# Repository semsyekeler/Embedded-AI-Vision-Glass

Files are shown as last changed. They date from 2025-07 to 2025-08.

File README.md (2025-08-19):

<!-- Bu bir test ve örnek README dosyasıdır. -->

<div align="center">
  <h1 align="center">Gömülü Yapay Zeka Görü Gözlüğü (EGG)</h1>
</div>

---

### 📜 İçindekiler

1.  [**Proje Hakkında**](#-proje-hakkında)
    -   *Projenin çıkış noktası ve misyonu.*
2.  [**Teknik Mimari**](#️-teknik-mimari)
    -   *Sistemin genel yapısı ve kullanılan teknolojiler.*
3.  [**Donanım Detayları ve Montaj**](#-donanım-detayları-ve-montaj)
    -   *Kullanılan bileşenler ve montaj süreci.*
4.  [**Canlı Demolar**](#-canlı-demolar-ve-vitrin)
    -   *Projenin çalıştığını gösteren videolar.*

---
<br>

## 🏆 Proje Hakkında

Bu proje, görme engelli bireylerin dünyayı algılama şeklini kökten değiştirmek amacıyla, tamamen kişisel imkanlarla sıfırdan hayata geçirilmiş bir teknoloji manifestosudur. Misyonumuz, sadece "engel var" diyen bir cihaz değil, kullanıcıya **"önündeki tabelada 'acil çıkış' yazıyor"** diyebilen, çevresini **anlamlandıran ve betimleyen** bir yardımcı yaratmaktır. Bu vizyon, uluslararası bir yarışmada alınan derece ile tescillenmiştir.

Projenin temel amacı, teknolojiyi kullanarak görsel dünyayı sesli bilgiye dönüştürmek ve bu sayede kullanıcı için daha erişilebilir bir çevre yaratmaktır.

<br>
<br>
<br>
<br>
<br>

## 🛠️ Teknik Mimari

EGG projesi, donanım, gömülü yazılım, bulut ve mobil katmanları bir araya getiren tam kapsamlı bir IoT çözümüdür. Projenin teknik kararlarını ve yapısını aşağıdaki notlu şema özetlemektedir.

<p align="center">
  Açıklamalı Devre Şeması
</p>

Sistemin kalbinde, görevleri verimli bir şekilde dağıtan **Çift Mikrodenetleyici Mimarisi** (ESP32 + ESP32-CAM) yer alır. Tüm ağır yapay zeka işlemleri, maliyeti ve cihaz yükünü en aza indirmek için **AWS (Amazon Web Services)** üzerinde "sunucusuz" bir mimaride çalışır.

<br>
<br>
<br>
<br>
<br>

### 🔩 Donanım Detayları ve Montaj

Bu bölümde, projenin fiziksel olarak nasıl hayata geçtiğini görebilirsiniz. Tüm bileşenler, bütçe dostu ve erişilebilir olmaları göz önünde bulundurularak seçilmiştir.

*   **Ana Kontrolcü:** ESP-WROOM-32
*   **Kamera İşlemcisi:** ESP32-CAM
*   **Güç Yönetimi:** TP4056 Şarj Modülü + 18650 Lityum Pil + 5V Step-Up Konvertör
*   **Ses Sistemi:** Modifiye edilmiş (hacklenmiş) bir Bluetooth kulaklık PCB'si

<p align="center">
  Montaj Aşaması
  <br>
  <em>Tüm bileşenlerin elle birleştirildiği "çıplak" prototipin ilk halleri.</em>
</p>

<br>
<br>
<br>
<br>
<br>

## 🖼️ Canlı Demolar ve Vitrin

Projenin işlevselliğini ve son halini gösteren YouTube videoları:

| Final Prototip Turu | Canlı Asistan Testi |
| :---: | :---: |
| _Gözlüğün son halinin her açıdan incelendiği ürün turu videosu._ | _Sesle etkinleştirilen fener özelliğinin canlı testini içeren demo videosu._ |
| <a href="https://www.youtube.com/watch?v=MX3VzD0-spU" target="_blank">Final Prototip Turu Videosu</a> | <a href="https://www.youtube.com/watch?v=o3IA8lo6HuY" target="_blank">Canlı Asistan Testi Videosu</a> |

<br>
<br>
<br>
<br>
<br>

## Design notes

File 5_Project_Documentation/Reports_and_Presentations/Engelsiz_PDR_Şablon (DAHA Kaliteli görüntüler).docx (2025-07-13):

# TEKNOFEST

# HAVACILIK, UZAY VE TEKNOLOJİ FESTİVALİ

ENGELSİZ YAŞAM TEKNOLOJİLERİ YARIŞMASI

PROJE DETAY RAPORU

## PROJE ADI: ENGELSİZ GÖRÜ GÖZLÜĞÜ (EGG)

TAKIM ADI: ŞAH

Başvuru ID: 446246

TAKIM SEVİYESİ: Lise

İçindekiler

1. Proje Özeti (Proje Tanımı)

EGG görme eyleminde sorun yaşayan bireylerin akıllı gözlük teknolojileriyle hayatlarını kolaylaştırmayı çalışıyor, görme eyleminde sorun yaşayan bireylerin hayatlarında yapay zeka destekli bir yardımcı oluyor.

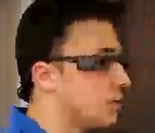
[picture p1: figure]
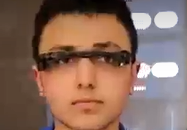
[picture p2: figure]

  1.1. Belge İçeriği

BUbelge şuanları içeriyor

  1.2. Tasarım

EGG’nin toplam ağırlığı 93g olmak üzere dış tasarımsal açıdan çok ilkel, gelişimini tamamlamamış halde EGG şuanda bir 3d sinema gözlüğünün çerçevesinin alt kısımlarının kesilmesiyle oluşturulmuş kasayı kullanıyor. Üzerinde sağ ve sol olmak üzere iki mantar LED bulunmakta üzerinde laptop batarya kutusundan çıkmış, ömrü azalmış, üzerinde 2Ah yazan bir adet 18650 batarya bulunmakta ve değiştirilebillir olması için 18650 batarya yatağı bulunmakta ve bataryanın şarj edilebilir olması için ve herhangi bir kısa devre vb. durumda korumuya da alması için bms devreli olan şarj devresi TP4056 bulunmakta ama micro usb soketi pil yatağının soluna konumladırılmış vaziyette -daha kolay şarj edilebilir olması açısından- . Üzerinde bir adet ESP32-WROOM bulunmakta ve bir adetESP32-CAM olarak adlandırılan geliştirme kartı bulunuyor ESP32’yi tercih etme sebeplerim uygun fiyatlı ve kablosuz iletişim kurma olanaklarını bünyesinde hazır olarak bulundurması (WiFi, Bluetooth 4.2, BLE), daha hızlı olması ve kapasitif ölçüm yapabilmesi. Normalde sadece ESP32-CAM yetecekken bir adet daha ESP32 kullanmamım sebebi ESP32-CAM üzerinde bulununan hafıza kartı soketini kullanınca I/O olarak kullanabileceğim pinin kalmaması ve ESP32-CAM ile WiFi üzerinden yayın yaparken Blutooth’u kullanmak istersem hata vermesiydi bunun üzerine iki adet ESP32 kullanarak birbirlerini de UART üzerinden haberleştirerek bu sorunu çözdüm. Üzerinde iki adet dokunmatik yüzey bulunuyor bu yüzeyleri ESP32’nin kapasitif ölçüm yapabilen pinleri ile kontrol ediyorum ve hem elimizle daha kolay erişebilinmesi hem de daha stabil çalışması adına yüzeyleri nikel şeritten parça keserek oluşturdum. Ses işlevleri içinse mikrofon kalitesi çok iyi olan, sesi çok iyi veren ve alan ve bu özelliklerine rağmen telefoncularda en ucuz alabileceğiniz seviyede olan bluetooth kulaklığı keşfettim ve kullandım hazır kullanmamın bana katkısı şu oldu hali hazırda ses kalitesi iyi olduğundan sesi yazıya çevirme işlemlerinde daha iyi tanımlama sağladı ama video çekimi yapacağım zaman mikrofon bluetooth kulaklıkta olduğundan ses alamayı eş zamanlı yapamadım. EGG özünde bir akıllı gözlük olduğundan akıllı gözlük gibi de kullanılabiliyor. Dokunmatik yüzey ilk başta bir adet vardı sadece akıllı gözlük işlevlerini yapıyordu yapay zeka fonksiyonlarını uygulama üzerinden buton ile ya da sesli asistan ile veriyorduk ama bu hem süreyi uzatıyordu hem de yolda giderken sesli bir şekilde söylenmesi iyi karşınmayacağından ikinci yüzeyi ekledim ve test ettim Arduino Uno’yu programlayıcı olarak kullanarak ESP32’ye test programını atıp yüzeyi test ettim.

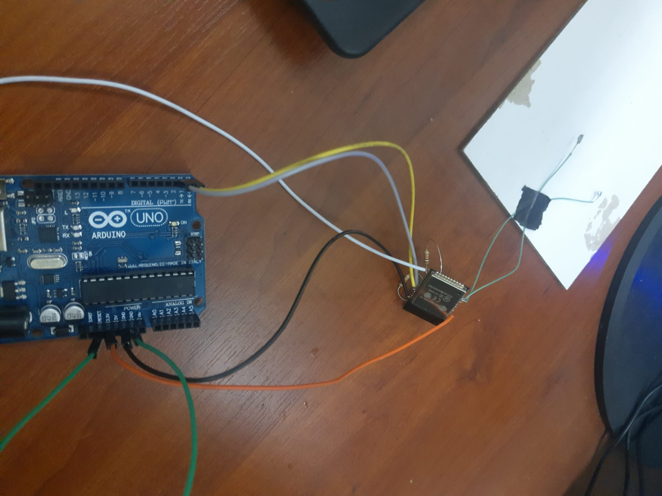
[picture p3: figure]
Yüzeyler

Sarı işaretli yerde olan şey ESP32, siyah işaretli olan yerse dokunmatik yüzeylerimiz.

Yüzeyler şöyle çalışıyordu her birinin 4 işlevi vardı tek dokunma, çift dokunma, üç dokunma ve basılı tutma ama gelin görünki tek yüzeyde çalışan bu mantık diğer yüzeyle olunca çalışmadı aslında sebebi interrupt kullanmamamdı kullanmayı denedim ama kapasitif ölçümde çalıştıramadım bu beni daha iyi bir sisteme itti buradaki sistem sabitti benimde aklıma değişebilir bir sistem geldi yine iki yüzey olacaktı ilk yüzey 4 işlevli olan sistemi kullanacaktı ama kullanırken çağıracağı fonksiyonlar index diye bir değişkene bağlı olacaktı bu sayede indexin değişimiyle dinamik fonksiyonları elde edecektim ikinci yüzey ise indexi arttıracaktı ve basılı tuttuğunda sıfırlayacaktı bunu bu şekilde yaparak dinamik fonksiyonları çalışır bir sisteme döktüm.

Dokunmatik yüzey ve işlevleri index değimine göre tablodaki gibidir

| İndex = 0 | İndex = 1 | İndex =2 | İndex =3
1. Dokunuş | Sesli Asistan | Sesli Asistan | Sesli Asistan | Sesli Asistan
2. Dokunnuş | Fotoğraf Çek | Ses başlat/durdur çağrıyı kabul et | Ortam Analizi | Para Tespiti
3. Dokunuş | Yayina Geç | Çağrıyı reddet | Metin Analizi | Yüz Tanıma
Basılı tutma | LED aç/kapa | Kulaklığı aç/kapa | Metin Çevirisi | Şu anda nerdeyim

Sesli asistan fonksiyonu Bluetooth ile bağladığımız telefona veri göndererek kodladığım sesli asistanı çağırır.

Fotoğraf Çek fonksiyonu sisteme fotoğrafı çekip ESP32-CAM'e taktığımız sd karta fotoğrafı kaydeder ve ismini çekildiği tarih ve saati olarak yazar.

LED aç/kapa fonksiyonu üzerinde bulunan mantar ledlerin durumu her neyse zıttına çevirir.

Ses başlat/durdur fonksiyonu çağrıyı kabul et fonksiyonu kulaklıklardan bildiğimiz play/pause işlevini görür.

Çağrıyı reddet fonksiyonu daha uzun süre kulaklığa tetik vererek çağrıyı reddeder.

Kulaklığı aç/kapa 3 saniye boy kulaklığa tetik vererek kulaklığı açar veya kapatır.

Ortam analizi fonksiyonu telefonun hotspotunu açar, fotoğraf çeker, sunucuya atar ve sunucuda işlenir sonra tespit edilen nesneleri sayılarıyla birlikte döndürür android uygulamaysa döndürülen bilgiyi alır ve okutur.

Metin analizi fonksiyonu telefonun hotspotunu açar, fotoğraf çeker, sunucuya atar ve sunucuda işlenir sonra tespit edilen metinleri okutur.

Metin çevirisi fonksiyonu aynı metin analizi ile aynı sistemi kullanır ama sesli okutmadan önce Google çeviriye metini yollar ve türkçeye çevirip okutur.

Para tespiti fonksiyonu telefonun hotspotunu açar, fotoğraf çeker, sunucuya atar ve sunucuda banknotu tespit eder ve sonucu telefona okutur örneğin; “200 türk lirası” şeklinde okutur.

Yüz tanıma fonksiyonu telefonun hotspotunu açar, fotoğraf çeker, sunucuya atar ve sunucuda yüz tespit edilir, yüz eğer evvelden tanıtılmışsa o kişi nasıl kaydedilmişse onun ismini okutur, eğer kaydedilmemişse o kişinin ismini söyleyip kayıt edebiliriz.

Komutları mobil uygulama ile de verebiliriz

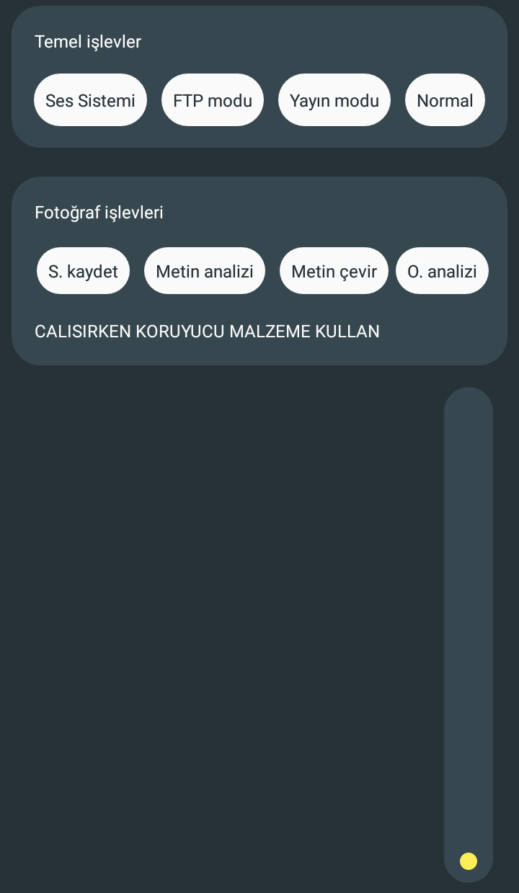
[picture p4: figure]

S. kaydet butonu fotoğrafı çeker ve linkini verir ve size fotoğrafı gösterir.

FTP modu butonu telefonun hotspotunu açar, ve gözlüğü ona bağlatır sonra sd kart dizinine erişmemizi sağlar.

Komutları sesli komut ile de verebiliriz ama hem gecikme hem de yanlış anlamalar sebebiyle yavaş ve yavan kalıyor.

Yazılım

Yazılım, tasarımdaki kısımları işletiyor işletme sistemin yukarıdan anlayabileceğiniz gibi yazılım kısmı temel olarak üç kısımdan oluşuyor; gözlükteki yazılım, mobil uygulamadaki ve sunucudaki yazılım.

Gözlüğün Yazılımı

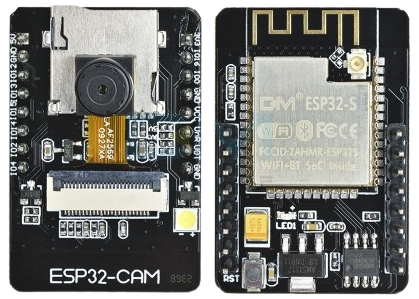
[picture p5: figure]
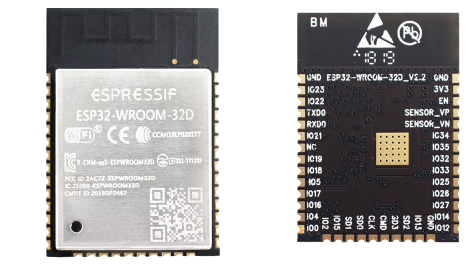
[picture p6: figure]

Gözlüğün yazılımı bu iki kartın içerisinde bulunuyor. Bu yazılımları mantıken ikiye ayırabiliriz; ilki kamera, WiFi ve SD kartı ile işlevleri kontrol eden kart yani ESP32-CAM diğeriyse ESP32-WROOM bu kart bileşenleri, Bluetooth’tan gelen verileri, Dokunmatik yüzeyleri ve ESP32-CAM'i kontrol eden kart. ESP32WROOM’a gelen veri eğer ESP32-CAM ile alakalı ise UART üzerinden iletir ve eğer oradan veri gelirse o veriyi alır telefona iletilecek ise iletir eğer kendisi kullanacaksa kullanır.

ESP32-WROOM' dan temel kodlar (Kodları okuyabilmek için büyütebilirsiniz)

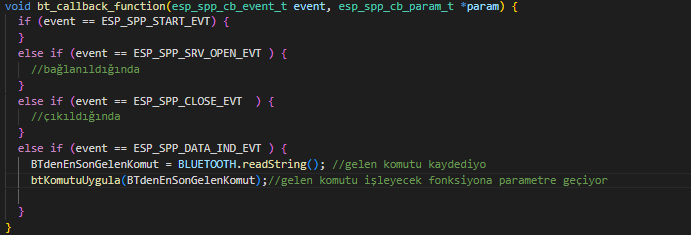
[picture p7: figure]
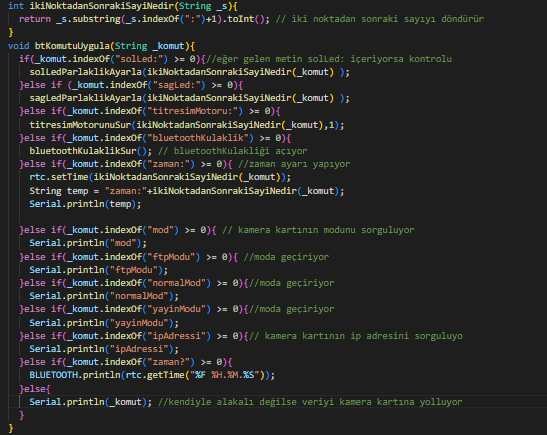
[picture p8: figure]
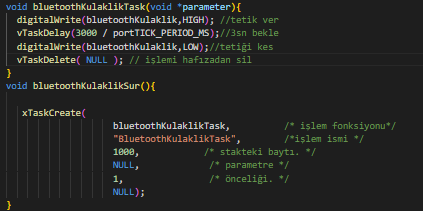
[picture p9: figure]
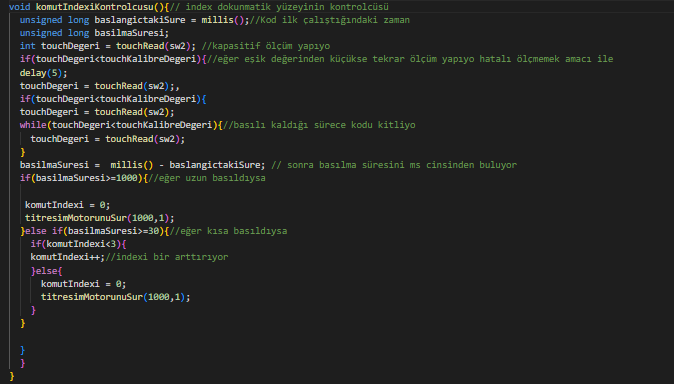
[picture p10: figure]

ESP32-CAM’den bazı temel kodlar

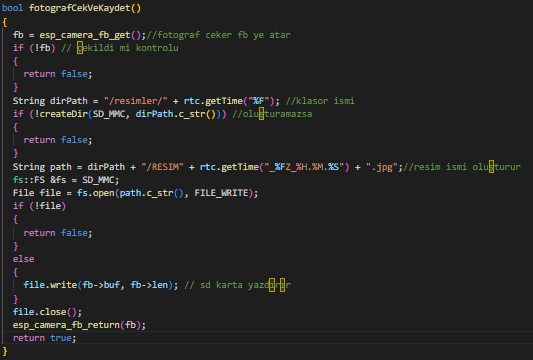
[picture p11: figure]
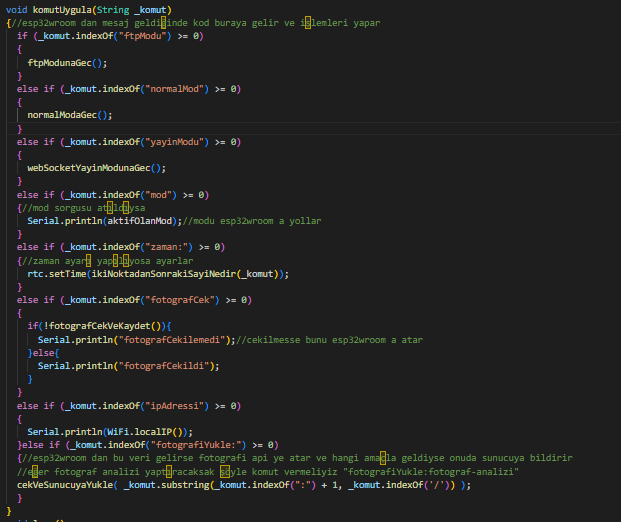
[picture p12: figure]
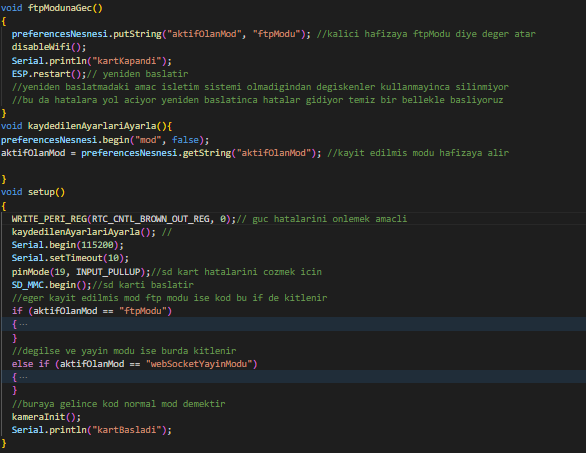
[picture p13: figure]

Mobil uygulama kodları

Mobil uygulama kodları temel olarak gözlükten gelen verileri alır işleve çevirir ya da emir verir ve sunucudan gelecek olan yanıtı bekler işlevler yaptırır

Arayüz kontrollerinin gozluge aktardığımız kodlar

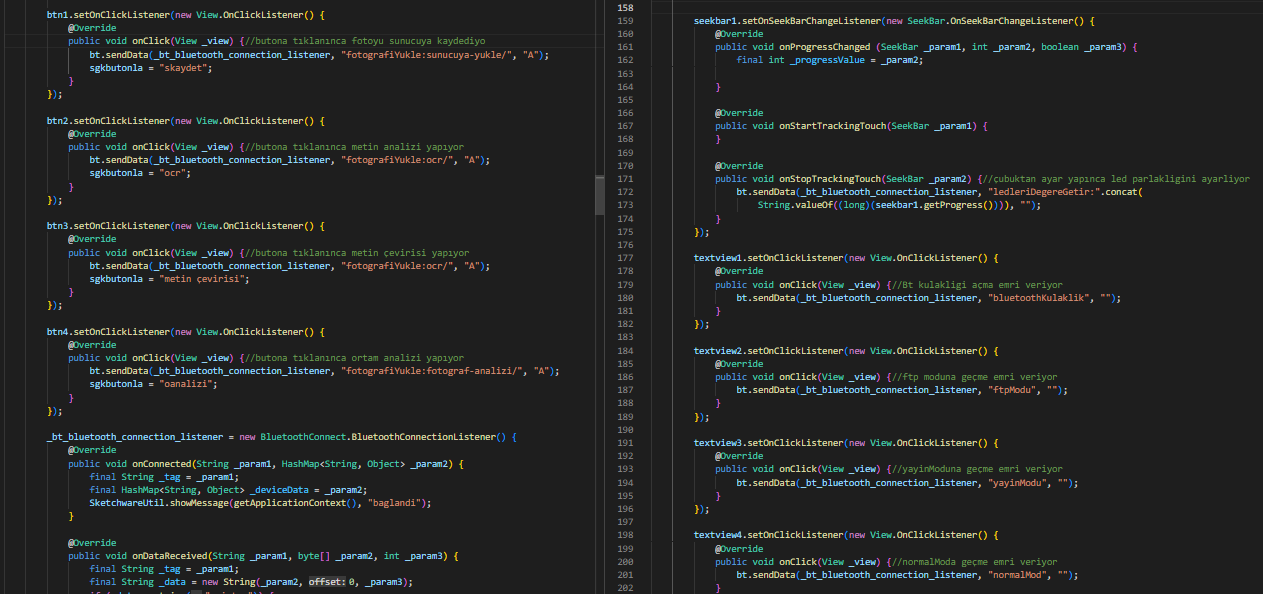
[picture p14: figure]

Sunucu yanıtına göre işlem yapan kodlar

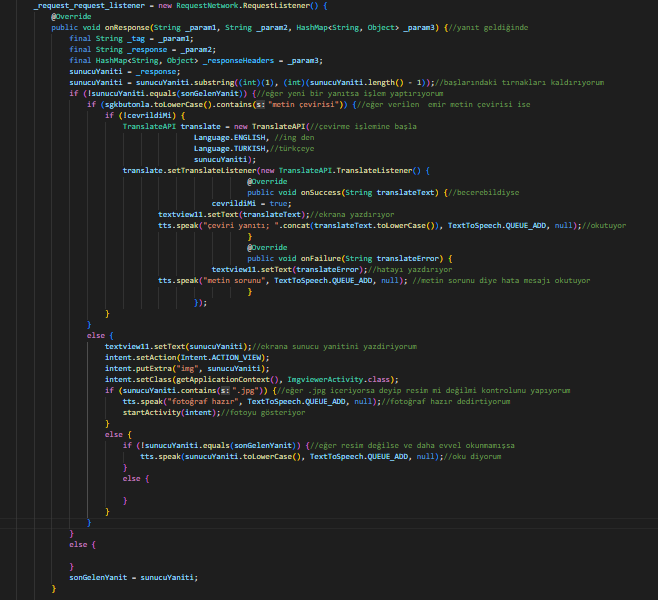
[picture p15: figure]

Sunucu kodları

Sunucu kodları Amazon Web Services de çalışmaktadır. AWS’nin birçok nimetinden yararlanmaktadır. Amazonu tercih etmemim sebebi 12 ay boyunca ücretsiz deneme hakkı sunmasıdır.

Fotoğraf işleme işlevleri

Gözlükten bir API isteğinde bulununca istek API Gateway’a ulaşır

Ulaştıktan sonra veri yukarıdaki gibi Json’a çevrilir. İstek atılırken ‘/’ karakterinden sonraki metin “amac” değişkenine atılır, yüklenen fotoğrafsa “base64Image” değişkenine atanır. Oluşturulan Json verisi AWS Lambda ya gelir yani JavaScript kodumuzun çalışacağı yere

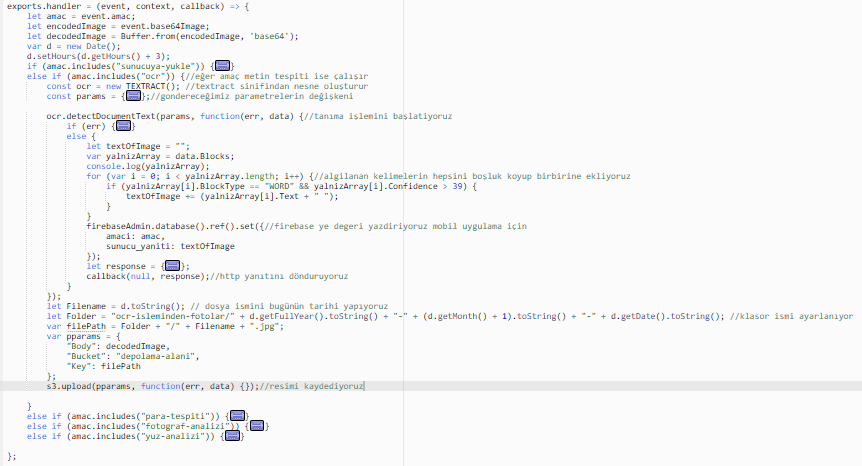
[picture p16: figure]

Burada amaca göre işlemler yaptırılır ve her işlemin sonucunda yüklenen fotograf S3 Bucket’ta saklanır.

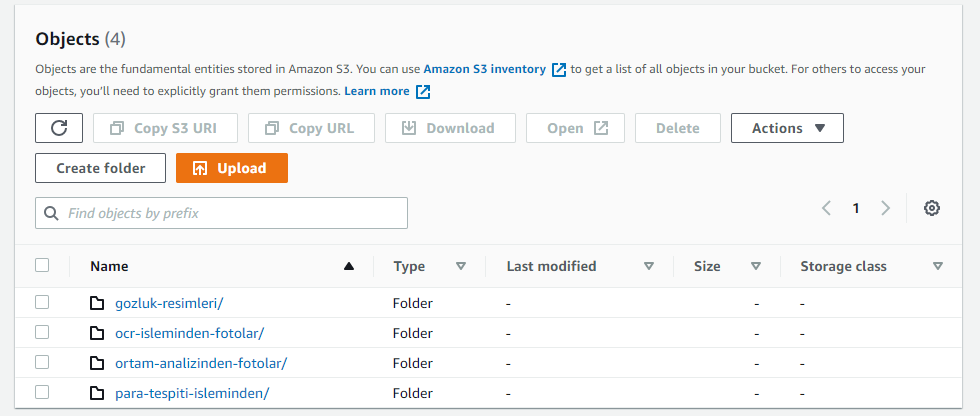
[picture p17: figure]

Fotoğraf yüklenince güncellenmiş yanıt

Yayın modu

Yayın yapabilmesi için bir Web Soket oluşturmamız lazım bunun için AWS’nin EC2, yani sanal bilgisayar hizmetini kullanıp aşağıdaki kodları çalıştırıyorum.

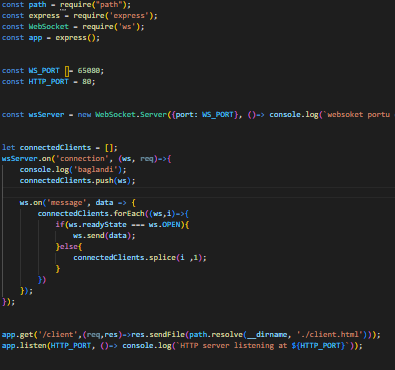
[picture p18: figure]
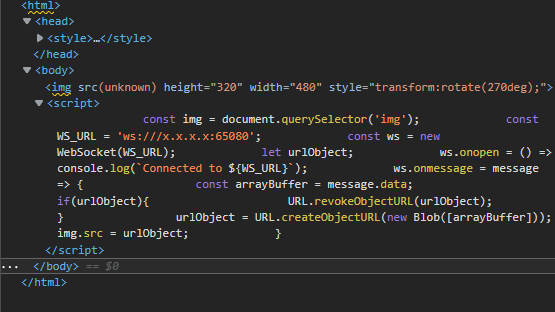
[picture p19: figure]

Eğer ssh ortamından çıkarsam kod çalışmıyordu araştırdım ama bulamamıştım teknik bir bilgiye bakarken nasıl çalışacağını buldum “Nohup command [arguments]: Sistemden çıktıktan sonra çalışmasına devam edecek şekilde verilen komutu çalıştırır.”[1]

Montaj

İlk olarak Bluetooth kulaklık kartına BC237 NPN transistörümü lehimledim base ucundan ESP32 ile tetik vereceğiz sonra kulaklık güç hattını bağladım ve kulaklığını bağladım ve sabitledim.

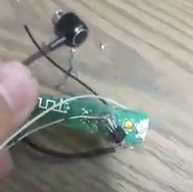
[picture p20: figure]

ESP32-WROOM'a gerekli dirençleri ekledim ve voltaj regülatorü devresini yaptım sonra ledleri bağladım, sonra titreşim motorunun önüne bir BC237 koyarak titreşim motoru devresini oluşturdum ve dokunmatik yüzeyin nikel şeritini bağladım ve sistemi sabitledim.

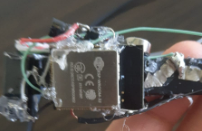
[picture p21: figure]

Sonra ESP32-CAM'i monte ettim ve iki kartı tx-rx rx-tx olacak şekilde birbirine bağladım.

Pil yatağı ile sürgülü anahtar bağlantılarını yaptım ordan gelen hattı step-up a bağladım şarj için devremi bağladım micro-usb soketimi pil yatağının yanına yerleştirdim ve çıkan kabloları gereken yerlere bağladım.

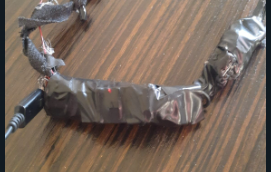
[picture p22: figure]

Son olarak gözlük şu şekilde gözüktü

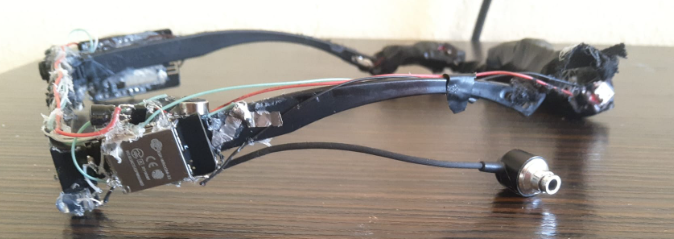
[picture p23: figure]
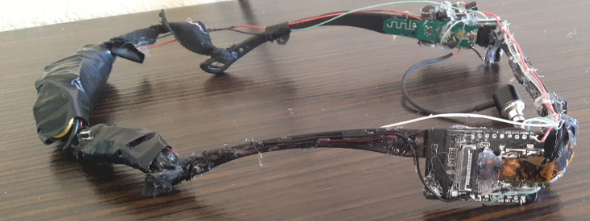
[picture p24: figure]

2. Problem Durumunun Tanımlanması:

Görme eyleminde sorun yaşayan bireylerin problemlerini çözmek amacıyla gözlüğü geliştirdim ve geliştiriyorum yaşadıkları problemler; Tek başlarına özgür birey olarak hareket edememeleri, ayrımcılığa tabi tutulmaları, dolandırılmaları , ticaret yapamamaları, normal bir bireyin yaparken onların yapamadığı her şeyi çözmeye çalışıyorum bu gözlük ile

Yapılmış projelerin çoğu bir bireyin çoğu ihtiyacını karşılamak konusunda yetersiz aklıyor örneğin yapılmış olan nesnenin ya da elbisenin rengini söyleyen aletler çoğunlukla tek fonksiyonellikten yetersiz kalmakta ya da mesafe ye göre öten gözlükler de çünkü tek fonksiyonları oluyor

3. Çözüm

Görme eyleminde sorun yaşayan bireylerin problemlerini çözmek amacıyla ben gözlük sistemine kamera takıp yapay zeka ile analiz ettirip bu durumları minimize etmeyi çözüm olarak buldum

Örneğin bir görme eyleminde sorun yaşayan birey ticaret yapmaya çalışırsa muhtemelen dolandırılıcaktır ya da okumak istediği her yazı onların okuyabileceği yazılmıyor o sebepten okuyamayacaktır bu sebepten kamera ile tespit yapıp ona anlatmak tarif etmek çözüm olacaktır

Şu anda gözlükle verilen komutlar ile sorunlara çare olmakta tasarımsal olarak daha ilkel aşamalarda ama geliştirilebilirliği çok yüksek

4. Yöntem

Kullandığım yöntem gözlüğe kamera takıp onu sunucuda işleyerek çözmeye çalışıyor. Yöntemim bilgisayar sistemleri ile yapay zekanın birleşimi sonucu akıllı gözlük sistemleri üzerine kurgulu. Yaptığım prototipte yaptıklarımın işe yaradığını ama gecikmenin çok fazla olduğunu gördüm 30 saniyelere çıkmakta ve düşük ışıkta yetersiz çalıştığını gördüm.

5. Yenilikçi (İnovatif) Yönü

Piyasa da gördüğüm ürünlerde mesafesel olarak ya da tek fonksiyonlu olarak yapılan sistemler gördüm akıllı gözlük sistemleriyse bazı yerde görme eyleminde sorun yaşayan insanların işine yarayabilir ama normal insanlar için daha işe yarar konumda

Proje görme eyleminde sorun yaşayan kişiler için daha hafif bir sistem olarak kalıyor

ve çoklu fonksiyonellik sağlıyor

6. Uygulanabilirlik

Proje bir gözlük boyutuna indirgendiğinden dolayı uygulanabilirliği çok yüksek uyuglanabilirlik açısından da bu cihaza, bir telefona (internete erişmek için) ve sunucu ya ihtiyaç duymakta bu sayede yeni tasarıma geçirdiğimde hem daha teknolojik bir cihaz olduğundan insanlar tarafından gösterilen ayrımcılık azalacaktır ve insanlar kendi kendilerine yetebileceğinden dolayı da azalacaktır.

7. Tahmini Maliyet ve Proje Zaman Planlaması

Ürün | Fiyat(tl)
18650 lipo | 80
Lipo yatağı | 10
AMS1117 | 2
ESP32 | 110
ESP32-CAM | 160
BT-KULAKLIK | 120
Titresim motoru | 8

  7.1. Bu kısımda ürünün tasarım, üretim ve test süreçlerini içeren bir zaman planlaması ve kullanılacak malzeme listesi hazırlanmalıdır.
  7.2. Proje planına bağlı olarak mali analiz gerçekleştirilmeli, hangi harcamaların hangi dönemde yapılacağı yazılmalıdır.

Piyasada benzer projeler var ama benimki gibi spesifik bir konuya odaklanmadığından net bir karşılaştırma yapabilmem mümkün değildir ama akıllı gözlük olarak karşılaştırcaksak 400$ fiyat segmentine çıkıyoruz.

  7.3. Proje takvimi bir zaman çubuğu üzerinde gösterilebilir. Ancak çok karmaşık olmamasına özen gösterilmelidir.
8. Proje Fikrinin Hedef Kitlesi (Kullanıcılar):

Görme eyleminde sorun yaşayan bireyler ve akıllı gözlük kullanmak isteyen insanlardır

9. Riskler

Projeyi olumsuz yönde etkileyebilcek unsurlar örneğin internetsiz bir ortamda bu gözlüğün yapay zeka fonksiyonları çalışmayacağından çalışmayacaktır, ve yapay zeka her ne kadar elimizin altında iyi çalışabilecek olsada problem doğurma ihtimalleri yine de yüksektir.

Bataryaların patlama riski az da olsa mümkündür ve kafamıza teknoloji getirince ve o saatler boyu kalınca onun getirebileceği riskler

Enerjilerle alakalı yaşanabilecek sorunlar herhangi bir kuvvete toza ya da suya dayanımıyla ilgili yaşanılabilcek problemler

Bataryanın ve Bataryanın izolasyonunda çok daha iyi ve kalite de olan malzemeler kullanılmalıdır. Yapay zeka da oluşabilecek problemleri ise insan bir yere kadar tolere ama ondan sonra oluşacak problemleri çözmek yeni modeller eğiterek mümkün olabilir

Toza ya da suya dayanımıyla ilgili problemleri de yeni tasarımlarla çözeceğim.

Riskler | Az | Orta | Çok
İnternet hataları | X
Toz/su/güneş | | X
Enerji dalgalanması | X
Batarya infilakı | | | X
Yapay zeka hataları | | X

10. Kaynaklar

[1] 2016, Teknik Bilgiler, EMO AJANDASI,108.syf

RAPOR TASLAKLARI İLE İLGİLİ NOT:

- Yukarıda yer alan ilk 9 madde en fazla 10 (On) sayfada anlatılacaktır.
- Kapak, açıklama ve görsel olmak üzere en fazla 15 sayfa olacaktır. 15 sayfayı geçen raporlar değerlendirmeye alınmayacaktır. (Kaynakça ve içindekiler sayfa sayısına dahil değildir.)
- Tüm raporlar akademik rapor standartlarına uygun olarak yazılmalıdır.
- Her rapor “kapak” ve “içindekiler” sayfası içermelidir.
- Yazı tipi: Times New Roman, Punto: 12, Satır Aralıkları: 1,15 , İki tarafa yaslı, Sayfa kenar boşlukları üst-alt-sağ-sol 2,5 cm olmalıdır.
- - Rapor içindeki cümleler birbirinin aynı ve tekrarı niteliğinde olmamalıdır.
- - Raporunda, web sitemizde yer alan geçmiş yıl raporlarından yararlanmış olan takımlar alıntı yaptığını ilgili sayfada belirtmesi gerekmektedir. Açıklamayı alıntı yapılan cümlenin ardından belirtmeniz gerekmektedir.
- ALINTI FORMATI: "Alıntı yapılan Cümle/ler" (Yıl, Yarışma Adı, Kategori, Takım Adı)
- ÖRNEK ALINTI: "Enkazda depremzedenin nerede olduğunu tespit edilememesi, enkaz kaldırma ve deprem-zede arama çalışmalarını yavaşlatan en önemli sorundur." (2020, İnsanlık Yararına Teknoloji Yarışması, Afet Yönetimi, X Takımı)

- Kaynakçada referanslar aşağıdaki şekilde belirtilebilir.

Dijital Kaynak: Yazarların Soyadı, Adlarının Baş Harfi., Yazının Başlığı, Yazının Tarihi, Erişim Tarihi, Erişim Adresi.

Basılı Kaynak: Yazarların Soyadı, Adlarının Baş Harfi., (Basım Tarihi) Yazının Başlığı, (Varsa) Yayınlandığı Derginin Adı, (Varsa) Derginin Sayısı, Sayfa numarası.

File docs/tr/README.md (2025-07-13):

# Gömülü Yapay Zeka Görü Gözlüğü (EGG)

<div align="center">

**Diğer Dillerde Oku**

<a href="../../README.md">🇺🇸 English</a> | <a href="./README.md">🇹🇷 Türkçe</a> | <a href="../de/README.md">🇩🇪 Deutsch</a> | <a href="../es/README.md">🇪🇸 Español</a> | <a href="../fr/README.md">🇫🇷 Français</a> | <a href="../ru/README.md">🇷🇺 Русский</a> | <a href="../zh-CN/README.md">🇨🇳 中文</a>

</div>

<!-- ANA GÖRSEL: İLK PROTOTİP ve BAŞARI YAN YANA, AÇIKLAMALARIYLA -->
<p align="center">
  <table>
    <tr>
      <td align="center" style="padding: 10px; border: none;">
        İlk Prototip
        <br>
        <em><b>Resim 1: Fikrin İlk Hali.</b> Elle lehimlenmiş modüller ve modifiye edilmiş bir gözlük çerçevesi ile hayata geçirilen ilk işlevsel prototip.</em>
      </td>
      <td align="center" style="padding: 10px; border: none;">
        Yarışma Başarısı
        <br>
        <em><b>Resim 2: Emeğin Tescillenmesi.</b> Sivas Uluslararası Robot Yarışması'nda Yapay Zeka kategorisinde kazanılan üçüncülük ödülü.</em>
      </td>
    </tr>
  </table>
</p>

### Misyonumuz

Bu proje, bir lise öğrencisinin, görme engelli bireylerin dünyayı algılama şeklini kökten değiştirmek amacıyla, tamamen kişisel imkanlarıyla sıfırdan hayata geçirdiği bir teknoloji manifestosudur. Misyonumuz, sadece "engel var" diyen bir cihaz değil, kullanıcıya **"önündeki tabelada 'acil çıkış' yazıyor"** diyebilen, çevresini **anlamlandıran ve betimleyen** bir yardımcı yaratmaktır. Bu vizyon, uluslararası bir yarışmada alınan derece ile tescillenmiştir.

Bu repo, projenin tüm yaşam döngüsünü detaylandıran kapsamlı bir teknik arşivdir.

**Yasal Uyarı:** Bu repodaki dosyalar yalnızca gösterim amaçlıdır. Tüm hakları saklıdır ve bu proje **açık kaynak değildir**.

---

### Proje Anatomisi ve Teknik Mimari

EGG projesi, donanım, gömülü yazılım, bulut ve mobil katmanları bir araya getiren tam kapsamlı bir IoT çözümüdür. Projenin teknik kararlarını ve yapısını aşağıdaki notlu şema özetlemektedir.

<p align="center">
  <a href="../../1_Hardware_Design/gozluk-sema-noted.jpg">Açıklamalı Devre Şeması</a>
  <br>
  <em>Notlu ve detaylı devre şemasını tam boyutta görmek için resme tıklayın.</em>
</p>

*   **Donanım ve Gömülü Yazılım:** Görevleri verimli bir şekilde dağıtan **Çift Mikrodenetleyici Mimarisi** (ESP32 + ESP32-CAM) kullanılmıştır. Ana kontrolcü arayüz ve Bluetooth'u yönetirken, özel işlemci kamera ve Wi-Fi görevlerini üstlenir.
*   **Sunucu Altyapısı (Bulut):** Tüm ağır yapay zeka işlemleri, maliyeti ve cihaz yükünü en aza indirmek için **AWS (Amazon Web Services)** üzerinde "sunucusuz" bir mimaride (Lambda, Textract, Rekognition) çalışır.
*   **Mobil Uygulama (Android):** Gözlüğü kontrol etmek ve işlenen sonuçları sesli olarak almak için geliştirilmiş kullanıcı dostu bir arayüzdür.

### Temel Yetenekler

*   **Metin Analizi (OCR):** Doküman ve tabelalardaki metinleri okur.
*   **Canlı Metin Çevirisi:** Yabancı metinleri çevirir ve seslendirir.
*   **Ortam Betimleme:** Çevredeki nesneleri tanır ve raporlar.
*   **Çift Kontrol Sistemi:** Hem gözlük üzerindeki dokunmatik yüzeyler hem de mobil uygulama üzerinden sesli komutlarla kontrol.
*   **Ek Modlar:** Canlı Video Yayını (WebSocket) ve FTP Sunucu Modu (Kablosuz dosya erişimi).

---

### ⚖️ Telif Hakkı ve Lisans

**© 2024, Şems YEKELER. Her Hakkı Saklıdır.**

Bu projenin kaynak kodları, donanım şemaları ve diğer tüm varlıkları yalnızca portfolyo ve gösterim amacıyla sunulmuştur. Kodları eğitim amacıyla inceleyebilirsiniz, ancak yazarın açık ve yazılı izni olmaksızın kopyalamanız, değiştirmeniz, dağıtmanız veya herhangi bir şekilde kullanmanız yasaktır.

**Bu proje açık kaynak değildir.**

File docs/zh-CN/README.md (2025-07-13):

# 嵌入式人工智能视觉眼镜 (EGG)

<div align="center">

**阅读其他语言版本**

<a href="../../README.md">🇺🇸 English</a> | <a href="../tr/README.md">🇹🇷 Türkçe</a> | <a href="../de/README.md">🇩🇪 Deutsch</a> | <a href="../es/README.md">🇪🇸 Español</a> | <a href="../fr/README.md">🇫🇷 Français</a> | <a href="../ru/README.md">🇷🇺 Русский</a> | <a href="./README.md">🇨🇳 中文</a>

</div>

<p align="center">
  嵌入式人工智能视觉眼镜
</p>

| **项目摘要** |
| :---: |
| 本项目记录了一名高中生如何仅凭个人资金，独立从零开始设计、构建和编码一个由人工智能驱动的智能眼镜原型。“嵌入式人工智能视觉眼镜”(EGG) 是一款屡获殊荣的辅助设备，旨在通过解读环境来增强视障人士的独立性。它通过物体识别、文本转语音和实时翻译，将抽象的视觉概念转化为有形信息。|

---
## 项目大纲

本项目通过5个主要章节记录了EGG的创建过程，每个章节都在其各自的文档中有详细说明：

*   **[第一章：构想与“初衷”](./../../5_Project_Documentation/1_The_Idea_and_The_Why.md)**
*   **[第二章：硬件架构与组装](./../../5_Project_Documentation/2_Hardware_Architecture.md)**
*   **[第三章：软件生态系统](./../../5_Project_Documentation/3_Software_Ecosystem.md)**
*   **[第四章：功能与现场演示](./../../5_Project_Documentation/4_Capabilities_and_Demos.md)**
*   **[第五章：竞赛、挑战与心得](./../../5_Project_Documentation/5_Competitions_and_Learnings.md)**

---

## ⚖️ 版权与许可

**© 2024, Şems YEKELER. 版权所有。**

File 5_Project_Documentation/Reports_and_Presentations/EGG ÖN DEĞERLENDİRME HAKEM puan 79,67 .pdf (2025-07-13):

# TEKNOFEST

## HAVACILIK, UZAY VE TEKNOLOJİ FESTİVALİ


## ENGELSİZ YAŞAM TEKNOLOJİLERİ

## ÖN DEĞERLENDİRME RAPORU

## TAKIM ADI ŞAH

## PROJE ADI

## ENGELSİZ GÖRÜ GÖZLÜĞÜ

## BAŞVURU ID: 446246

## İÇİNDEKİLER

### 1. Proje Özeti

### 1.1. Engelsiz Görü Gözlüğü; özel gereksinimli bireylerin toplumda yaşadıkları

sorunları ele alarak bağımsız yaşamlarını sağlamak amacıyla bilgisayar sistemlerini kullanarak onlara destek sunan gözlük sistemidir.

### 2. Proje Fikrinin Açıklanması

### 2.1. Çözüm Ürettiği Sorun / İhtiyaç

2.1.1.
- Projeyi görme eyleminde sorun yaşayan kişilerin günlük hayatlarında sorun yaşamayan kişilere göre yaşadıkları zorlukları çözmek için geliştirdim. Sorunlarsa; çoğu yazının sorun yaşamayan insanların okuyabileceği şekilde yazılması, sorun yaşayan insanların yaşamayanlara kıyasla eşitsizliği, “Sokağınızın kaldırımında diğer insanlar gibi ilerleyemezken, bir toplu taşıma aracına binmeye çalışıp da bunu başaramazken, eğitiminizi sürdüremezken, iş bulamazken, tek başınıza özgürce, kendinize yeterek yaşamınızı sürdüremezken karşınıza çıkan, ayrımcı uygulamalardır aslında.” [1] diyebiliriz…
- Bu sorunları çözmek amacıyla EGG’yi geliştirdim. EGG yani Engelsiz Görü Gözlüğü üzerinde var olan donanımlarıyla aldığı görüntüyü işler ve görüntüdeki metinleri tespit edip metin analizi yapıp okuyabilir, metin çevirisi yapıp okuyabilir, ortamı betimleyip ortamda bulunan nesneleri sayısı ve renkleriyle bildirebilir, yüz analizi yapıp daha evvelden tanımladığınız kişileri tanıyabilir. Ulaşımda olan engelleri aşmak içinse GPS sistemleri ile birlikte aktif yapay zeka sistemini kullanarak akıllı bir şekilde trafikte olan yaya ışık durumuna kadar bilgi verip kişiyi istediği yere güvenli bir şekilde götürür.
- Bu problemlerin engelsiz yaşam için önemi çok büyüktür çünkü bu problemler yüzünden bu problemlere sahip olmayan insanlar gibi yaşayamazlar ve hayatın her noktasında da bu tekrarlanır… Çözümümün önemi ise problemlerin öneminin büyük olmasından önemi büyük oluyor. EGG, problemlerin çoğuna çözüm üretiyor.

### 2.2. Yerlilik ve Özgünlük Tarafı

### 2.2.1. EGG’nin yenilikçi ve özgün tarafları; EGG piyasada var olan

sistemler gibi kablo ile cepte olan sisteme bağlanmaz ve EGG bu işi kafada bitirir, EGG aktif yapay zeka modu ile alışılmış navigasyon sistemini ortamı analiz ederek çok daha işlevsel ve güvenli hale getirir, EGG sunucu tabanlı çalışır ve bunun sonucunda maliyet düşük olur ve geliştirmeler kolay, hızlı ve daha iyi yapılabilir

### 2.2.2. Proje tasarımı ve yazılımını ben oluşturdum. EGG’nin katkıları

2.1.1. deki sorunlara sahip bireylerin normal bir insan düzeyine erişebilmesini amaçladığından bireyleri topluma kazandırarak ülkemize maddi manevi katkılarla gelecektir.

### 2.3. Hedef Kitle

### 2.3.1. EGG’nin hedef kitlesi; Görme güçlüğünden problem yaşayan

bireyler ve 2.1.1. maddede olan problemleri yaşayanlar ve EGG’yi

kullanmak isteyenler.

### 3. Kullanılacak Yöntem

3.1.EGG donanım kısmında şu özelliklere sahiptir; kulaklığı, mikrofonu, dokunmatik yüzeyi, Bluetooth entegresi, WiFi entegresi, kamerası, ledleri, SD kart girişi, Titreşim motoru, batarya ve batarya şarj sistemi ve kontrolcüler. Tasarladığım yöntemi özetleyeyim. Kamera işlevi ve SD kart sistemini bir kartta topladım, ve diğer donanımsal işlevleri başka kartta sebebiyse kamera işlemlerinin daha az gecikmede olması ve SD kartı sistemde tek kamera ile alakalı işlevlerde kullanmamız ve donanım için yeterli G/Ç pini kalmamasıydı. Dokunmatik yüzeye fonksiyonlar ekledim 1 defa tıklayınca uygulamamın asistanını uyandırıyor 2 defa tıklarsam kamera kartına fotoğraf çekme emrini veriyor ve SD karta yazdırıyor 3 kere tıklarsam yayın moduna geçip cihaz kamerasıyla yayın yapıyor ve eğer basılı tutarsam normal moda geçiyor. İleride yayın moduna yayını işleyen yapay zeka sistemini entegre edeceğim. Asistan uyanınca mikrofonu üzerinden komutumuzu dinliyor ve sonuca göre işlemleri uyguluyor örnek verecek olursak ‘fotoğraf analizi’ deyince fotoğraf çekme emri gidiyor ve kart WiFi ile internete bağlanarak fotoğrafı sunucuya atıyor ve orada işliyoruz ve sonucu telefondaki uygulama ile sesli bir şekilde okutuyoruz bu sayede işlem yükü sunucuda olduğundan maliyeti aza indirip performansı yükseltmiş oluyoruz bu sayede teknolojinin hedef kitlesine erişimini kolaylaştırıyoruz. İleride bu işlevleri sesli emir vermeden de yaparak hem daha hızlı hem de diğer kişilerin garipsememesi için başka bir dokunmatik yüzey eklemeyi düşünüyorum.

### 4. Proje Takvimi

Aylara göre yapılacaklar

Yapılacak Faaliyetler | Mart Haftalar | Nisan Haftalar | Mayıs Haftalar
Literatür Taraması | x | x
Kavramsal Tasarım | | | x | x
Elektronik kontrol ünitesi iyileştirme | | | | | x | x
Aktif yapay zekâ Eklentisi | | | | | | | x | x | x
Test,İyileştirmeler & Sunuş | | | | | | | | | | x | x | x

### 5. Kaynakça

### [1] Akbulut, Süleyman (2012), “Gerçekten Eşit miyiz? Acı(ma), Zayıf Gör(me) ve Yok

Say(ma) Ekseninde Engelli Ayrımcılığı”, Ayrımcılık: Çok Boyutlu Yaklaşımlar,

### (Derleyenler: Kenan Çayır ve Müge Ayan-Ceylan), (İstanbul: İstanbul Bilgi

Üniversitesi Yayınları), 149-162.

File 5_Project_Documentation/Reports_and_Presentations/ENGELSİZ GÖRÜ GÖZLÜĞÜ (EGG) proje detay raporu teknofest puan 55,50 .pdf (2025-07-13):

## TEKNOFEST

## HAVACILIK, UZAY VE TEKNOLOJİ FESTİVALİ

## ENGELSİZ YAŞAM TEKNOLOJİLERİ YARIŞMASI

## PROJE DETAY RAPORU

## PROJE ADI: ENGELSİZ GÖRÜ GÖZLÜĞÜ (EGG)

## TAKIM ADI: ŞAH

## Başvuru ID: 446246

## TAKIM SEVİYESİ: Lise

İçindekiler

### 1. Proje Özeti (Proje Tanımı)

EGG görme eyleminde sorun yaşayan bireylerin akıllı gözlük teknolojileriyle hayatlarını kolaylaştırmayı çalışıyor, görme eyleminde sorun yaşayan bireylerin hayatlarında yapay zeka destekli bir yardımcı oluyor.


### 1.1. Belge İçeriği

BUbelge şuanları içeriyor
1.2.Tasarım

EGG’nin toplam ağırlığı 93g olmak üzere dış tasarımsal açıdan çok ilkel, gelişimini tamamlamamış halde EGG şuanda bir 3d sinema gözlüğünün çerçevesinin alt kısımlarının kesilmesiyle oluşturulmuş kasayı kullanıyor. Üzerinde sağ ve sol olmak üzere iki mantar LED bulunmakta üzerinde laptop batarya kutusundan çıkmış, ömrü azalmış, üzerinde 2Ah yazan bir adet 18650 batarya bulunmakta ve değiştirilebillir olması için 18650 batarya yatağı bulunmakta ve bataryanın şarj edilebilir olması için ve herhangi bir kısa devre vb. durumda korumuya da alması için bms devreli olan şarj devresi TP4056 bulunmakta ama micro usb soketi pil yatağının soluna konumladırılmış vaziyette -daha kolay şarj edilebilir olması açısından- . Üzerinde bir adet ESP32-WROOM bulunmakta ve bir adetESP32-CAM olarak adlandırılan geliştirme kartı bulunuyor ESP32’yi tercih etme sebeplerim uygun fiyatlı ve kablosuz iletişim kurma olanaklarını bünyesinde hazır olarak bulundurması (WiFi, Bluetooth 4.2, BLE), daha hızlı olması ve kapasitif ölçüm yapabilmesi. Normalde sadece ESP32-CAM yetecekken bir adet daha ESP32 kullanmamım sebebi ESP32-CAM üzerinde bulununan hafıza kartı soketini kullanınca I/O olarak kullanabileceğim pinin kalmaması ve ESP32-CAM ile WiFi üzerinden yayın yaparken Blutooth’u kullanmak istersem hata vermesiydi bunun üzerine iki adet ESP32 kullanarak birbirlerini de UART üzerinden
haberleştirerek | bu sorunu çözdüm. Üzerinde iki adet dokunmatik yüzey bulunuyor bu
yüzeyleri ESP32’nin kapasitif ölçüm yapabilen pinleri ile kontrol ediyorum ve hem elimizle daha kolay erişebilinmesi hem de daha stabil çalışması adına yüzeyleri nikel şeritten parça keserek oluşturdum. Ses işlevleri içinse mikrofon kalitesi çok iyi olan, sesi çok iyi veren ve alan ve bu özelliklerine rağmen telefoncularda en ucuz alabileceğiniz seviyede olan bluetooth kulaklığı keşfettim ve kullandım hazır kullanmamın bana katkısı şu oldu hali hazırda ses kalitesi iyi olduğundan sesi yazıya çevirme işlemlerinde daha iyi tanımlama sağladı ama video çekimi yapacağım zaman mikrofon bluetooth kulaklıkta olduğundan ses alamayı eş zamanlı yapamadım. EGG özünde bir akıllı gözlük olduğundan akıllı gözlük gibi de kullanılabiliyor. Dokunmatik yüzey ilk başta bir adet vardı sadece akıllı gözlük işlevlerini yapıyordu yapay zeka fonksiyonlarını uygulama üzerinden buton ile ya da sesli asistan ile veriyorduk ama bu hem süreyi uzatıyordu hem de yolda giderken sesli bir şekilde söylenmesi iyi karşınmayacağından ikinci yüzeyi ekledim ve test ettim Arduino Uno’yu programlayıcı olarak kullanarak ESP32’ye test programını atıp yüzeyi test ettim.


Sarı işaretli yerde olan şey ESP32, siyah işaretli olan yerse dokunmatik yüzeylerimiz. Yüzeyler şöyle çalışıyordu her birinin 4 işlevi vardı tek dokunma, çift dokunma, üç dokunma ve basılı tutma ama gelin görünki tek yüzeyde çalışan bu mantık diğer yüzeyle olunca çalışmadı aslında sebebi interrupt kullanmamamdı kullanmayı denedim ama kapasitif ölçümde çalıştıramadım bu beni daha iyi bir sisteme itti buradaki sistem sabitti benimde aklıma değişebilir bir sistem geldi yine iki yüzey olacaktı ilk yüzey 4 işlevli olan sistemi kullanacaktı ama kullanırken çağıracağı fonksiyonlar index diye bir değişkene bağlı olacaktı bu sayede indexin değişimiyle dinamik fonksiyonları elde edecektim ikinci yüzey ise indexi arttıracaktı ve basılı tuttuğunda sıfırlayacaktı bunu bu şekilde yaparak dinamik fonksiyonları çalışır bir sisteme döktüm.

Dokunmatik yüzey ve işlevleri index değimine göre tablodaki gibidir

| İndex = 0 | İndex = 1 | İndex =2 | İndex =3
1. Dokunuş | Sesli Asistan | Sesli Asistan | Sesli Asistan | Sesli Asistan
2. Dokunnuş | Fotoğraf Çek | Ses başlat/durdur çağrıyı kabul et | Ortam Analizi | Para Tespiti
3. Dokunuş | Yayina Geç | Çağrıyı reddet | Metin Analizi | Yüz Tanıma
Basılı tutma | LED aç/kapa | Kulaklığı aç/kapa | Metin Çevirisi | Şu anda nerdeyim

Sesli asistan fonksiyonu Bluetooth ile bağladığımız telefona veri göndererek kodladığım sesli asistanı çağırır.
Fotoğraf Çek fonksiyonu sisteme fotoğrafı çekip ESP32-CAM'e taktığımız sd karta fotoğrafı kaydeder ve ismini çekildiği tarih ve saati olarak yazar.
LED aç/kapa fonksiyonu üzerinde bulunan mantar ledlerin durumu her neyse zıttına çevirir.

Ses başlat/durdur fonksiyonu çağrıyı kabul et fonksiyonu kulaklıklardan bildiğimiz play/pause işlevini görür.
Çağrıyı reddet fonksiyonu daha uzun süre kulaklığa tetik vererek çağrıyı reddeder. Kulaklığı aç/kapa 3 saniye boy kulaklığa tetik vererek kulaklığı açar veya kapatır.

Ortam analizi fonksiyonu telefonun hotspotunu açar, fotoğraf çeker, sunucuya atar ve sunucuda işlenir sonra tespit edilen nesneleri sayılarıyla birlikte döndürür android uygulamaysa döndürülen bilgiyi alır ve okutur.

Metin analizi fonksiyonu telefonun hotspotunu açar, fotoğraf çeker, sunucuya atar ve sunucuda işlenir sonra tespit edilen metinleri okutur.

Metin çevirisi fonksiyonu aynı metin analizi ile aynı sistemi kullanır ama sesli okutmadan önce Google çeviriye metini yollar ve türkçeye çevirip okutur.

Para tespiti fonksiyonu telefonun hotspotunu açar, fotoğraf çeker, sunucuya atar ve sunucuda banknotu tespit eder ve sonucu telefona okutur örneğin; “200 türk lirası” şeklinde okutur.

Yüz tanıma fonksiyonu telefonun hotspotunu açar, fotoğraf çeker, sunucuya atar ve sunucuda yüz tespit edilir, yüz eğer evvelden tanıtılmışsa o kişi nasıl kaydedilmişse onun ismini okutur, eğer kaydedilmemişse o kişinin ismini söyleyip kayıt edebiliriz.

Komutları mobil uygulama ile de verebiliriz


S. kaydet butonu fotoğrafı çeker ve linkini verir ve size fotoğrafı gösterir.

FTP modu butonu telefonun hotspotunu açar, ve gözlüğü ona bağlatır sonra sd kart dizinine erişmemizi sağlar.

Komutları sesli komut ile de verebiliriz ama hem gecikme hem de yanlış anlamalar sebebiyle yavaş ve yavan kalıyor.

Yazılım
Yazılım, tasarımdaki kısımları işletiyor işletme sistemin yukarıdan anlayabileceğiniz gibi yazılım kısmı temel olarak üç kısımdan oluşuyor; gözlükteki yazılım, mobil uygulamadaki ve sunucudaki yazılım.
Gözlüğün Yazılımı


Gözlüğün yazılımı bu iki kartın içerisinde bulunuyor. Bu yazılımları mantıken ikiye ayırabiliriz; ilki kamera, WiFi ve SD kartı ile işlevleri kontrol eden kart yani ESP32-CAM diğeriyse ESP32-WROOM bu kart bileşenleri, Bluetooth’tan gelen verileri, Dokunmatik yüzeyleri ve ESP32-CAM'i kontrol eden kart. ESP32WROOM’a gelen veri eğer ESP32-CAM ile alakalı ise UART üzerinden iletir ve eğer oradan veri gelirse o veriyi alır telefona iletilecek ise iletir eğer kendisi kullanacaksa kullanır.

ESP32-WROOM' dan temel kodlar (Kodları okuyabilmek için büyütebilirsiniz)



ESP32-CAM’den bazı temel kodlar


Mobil uygulama kodları
Mobil uygulama kodları temel olarak gözlükten gelen verileri alır işleve çevirir ya da emir verir ve sunucudan gelecek olan yanıtı bekler işlevler yaptırır

Arayüz kontrollerinin gozluge aktardığımız kodlar

Sunucu yanıtına göre işlem yapan kodlar

Sunucu kodları
Sunucu kodları Amazon Web Services de çalışmaktadır. AWS’nin birçok nimetinden yararlanmaktadır. Amazonu tercih etmemim sebebi 12 ay boyunca ücretsiz deneme hakkı

sunmasıdır.
Fotoğraf işleme işlevleri
Gözlükten bir API isteğinde bulununca istek API Gateway’a ulaşır

Ulaştıktan sonra veri yukarıdaki gibi Json’a çevrilir. İstek atılırken ‘/’ karakterinden sonraki metin “amac” değişkenine atılır, yüklenen fotoğrafsa “base64Image” değişkenine atanır. Oluşturulan Json verisi AWS Lambda ya gelir yani JavaScript kodumuzun çalışacağı yere


Burada amaca göre işlemler yaptırılır ve her işlemin sonucunda yüklenen fotograf S3 Bucket’ta saklanır.


Fotoğraf yüklenince güncellenmiş yanıt

Yayın modu
Yayın yapabilmesi için bir Web Soket oluşturmamız lazım bunun için AWS’nin EC2, yani sanal bilgisayar hizmetini kullanıp aşağıdaki kodları çalıştırıyorum.


Eğer ssh ortamından çıkarsam kod çalışmıyordu araştırdım ama bulamamıştım teknik bir bilgiye bakarken nasıl çalışacağını buldum “Nohup command [arguments]: Sistemden çıktıktan sonra çalışmasına devam edecek şekilde verilen komutu çalıştırır.”[1]

Montaj
İlk olarak Bluetooth kulaklık kartına BC237 NPN transistörümü lehimledim base ucundan ESP32 ile tetik vereceğiz sonra kulaklık güç hattını bağladım ve kulaklığını bağladım ve sabitledim.


ESP32-WROOM'a gerekli dirençleri ekledim ve voltaj regülatorü devresini yaptım sonra ledleri bağladım, sonra titreşim motorunun önüne bir BC237 koyarak titreşim motoru devresini oluşturdum ve dokunmatik yüzeyin nikel şeritini bağladım ve sistemi sabitledim.


Sonra ESP32-CAM'i monte ettim ve iki kartı tx-rx rx-tx olacak şekilde birbirine bağladım.
Pil yatağı ile sürgülü anahtar bağlantılarını yaptım ordan gelen hattı step-up a bağladım şarj için devremi bağladım micro-usb soketimi pil yatağının yanına yerleştirdim ve çıkan kabloları gereken yerlere bağladım.


Son olarak gözlük şu şekilde gözüktü

### 2. Problem Durumunun Tanımlanması:

Görme eyleminde sorun yaşayan bireylerin problemlerini çözmek amacıyla gözlüğü geliştirdim ve geliştiriyorum yaşadıkları problemler; Tek başlarına özgür birey olarak hareket edememeleri, ayrımcılığa tabi tutulmaları, dolandırılmaları , ticaret yapamamaları, normal bir bireyin yaparken onların yapamadığı her şeyi çözmeye çalışıyorum bu gözlük ile
Yapılmış projelerin çoğu bir bireyin çoğu ihtiyacını karşılamak konusunda yetersiz aklıyor örneğin yapılmış olan nesnenin ya da elbisenin rengini söyleyen aletler çoğunlukla tek fonksiyonellikten yetersiz kalmakta ya da mesafe ye göre öten gözlükler de çünkü tek fonksiyonları oluyor

### 3. Çözüm

Görme eyleminde sorun yaşayan bireylerin problemlerini çözmek amacıyla ben gözlük sistemine kamera takıp yapay zeka ile analiz ettirip bu durumları minimize etmeyi çözüm olarak buldum

Örneğin bir görme eyleminde sorun yaşayan birey ticaret yapmaya çalışırsa muhtemelen dolandırılıcaktır ya da okumak istediği her yazı onların okuyabileceği yazılmıyor o sebepten okuyamayacaktır bu sebepten kamera ile tespit yapıp ona anlatmak tarif etmek çözüm olacaktır


Şu anda gözlükle verilen komutlar ile sorunlara çare olmakta tasarımsal olarak daha ilkel aşamalarda ama geliştirilebilirliği çok yüksek

### 4. Yöntem

Kullandığım yöntem gözlüğe kamera takıp onu sunucuda işleyerek çözmeye çalışıyor. Yöntemim bilgisayar sistemleri ile yapay zekanın birleşimi sonucu akıllı gözlük sistemleri üzerine kurgulu. Yaptığım prototipte yaptıklarımın işe yaradığını ama gecikmenin çok fazla olduğunu gördüm 30 saniyelere çıkmakta ve düşük ışıkta yetersiz çalıştığını gördüm.

### 5. Yenilikçi (İnovatif) Yönü

Piyasa da gördüğüm ürünlerde mesafesel olarak ya da tek fonksiyonlu olarak yapılan sistemler gördüm
Projenin özgün yönleri belirtilmelidir. Ek olarak, tasarlanan özgün ürünün donanımsal ve yazılımsal parçaları hakkında(varsa) bilgi verilmelidir.
5.1. Çalışmada, kodlarda ve tasarımda yenilikçi bir yön varsa mutlaka belirtilmelidir. Takımlar bu alanda kendi çalışmalarını nasıl bir yöntemle hazırladığını, benzer çalışmalardan hangi yönleri ile ayrıldığını açık ve net bir şekilde detaylı olarak belirtmelidir.

### 6. Uygulanabilirlik

6.1. Proje fikrinin hayata nasıl geçirileceği ve mevcut şartlar altında projenin ticari bir ürüne dönüştürülebilir olup olmadığı hakkında bilgi verilmelidir. Uygulanabilir olduğunda risk analizi yapılarak, mevcut risklerin neler olduğu da belirtilmelidir. (Risk analizi 9.bölümde detaylandırılabilir.)
6.2.

### 7. Tahmini Maliyet ve Proje Zaman Planlaması

Projenin en az maliyetle uygulanabilir olma durumu ve tahmini bütçesi hakkında bilgi verilmelidir.
7.1. Bu kısımda ürünün tasarım, üretim ve test süreçlerini içeren bir zaman planlaması ve kullanılacak malzeme listesi hazırlanmalıdır.

7.2. Proje planına bağlı olarak mali analiz gerçekleştirilmeli, hangi harcamaların hangi dönemde yapılacağı yazılmalıdır.
Piyasada benzer projeler varsa piyasadaki diğer projelerle birlikte maliyet karşılaştırması yapılmalıdır.
7.3. Proje takvimi bir zaman çubuğu üzerinde gösterilebilir. Ancak çok karmaşık olmamasına özen gösterilmelidir.

### 8. Proje Fikrinin Hedef Kitlesi (Kullanıcılar):

8.1. Projenin kimler tarafından kullanılacağı ve kimlere hitap edeceği burada belirtilmelidir.
8.2. Problemi yaşayanların kimler olduğu hakkında kısaca bilgi verilmelidir.

### 9. Riskler

Projeyi olumsuz yönde etkileyecek unsurların (risklerin) tespit edilmesi gerekmektedir. Proje hayata geçirilirken ortaya çıkabilecek problemler tanımlanmalıdır.
Proje hayata geçirilirken ortaya çıkabilecek problemlere yönelik tedbirlerin, çözüm önerilerinin
(B Planı) tanımlaması yapılmalıdır.
Zaman planlamasında iş paketleri, iş tanımları ve süreçleri ayrıntılı bir şekilde açıklanmalıdır.
Zamanlama ve bütçe planlaması ile ilgili olarak risk analizleri yapılmalıdır.
Risk planlamasında olasılık ve etki matrisi eklenmelidir. Olasılık ve Etki matrisi, her riskin gerçekleşme olasılığını ve proje hedeflerine etkisini değerlendirmeye yarayacaktır. Olasılık ve etki belirli gruplara (Az-Normal-Çok vb) ayrılmalıdır.

### 10. Kaynaklar

[1] 2016, Teknik Bilgiler, EMO AJANDASI,108.syf

RAPOR TASLAKLARI İLE İLGİLİ NOT:

- Yukarıda yer alan ilk 9 madde en fazla 10 (On) sayfada anlatılacaktır.
- Kapak, açıklama ve görsel olmak üzere en fazla 15 sayfa olacaktır. 15 sayfayı geçen raporlar değerlendirmeye alınmayacaktır. (Kaynakça ve içindekiler sayfa sayısına dahil değildir.)
- Tüm raporlar akademik rapor standartlarına uygun olarak yazılmalıdır.
- Her rapor “kapak” ve “içindekiler” sayfası içermelidir.
- Yazı tipi: Times New Roman, Punto: 12, Satır Aralıkları: 1,15 , İki tarafa yaslı, Sayfa

kenar boşlukları üst-alt-sağ-sol 2,5 cm olmalıdır.

- - Rapor içindeki cümleler birbirinin aynı ve tekrarı niteliğinde olmamalıdır.
- - Raporunda, web sitemizde yer alan geçmiş yıl raporlarından yararlanmış olan takımlar alıntı yaptığını ilgili sayfada belirtmesi gerekmektedir. Açıklamayı alıntı yapılan cümlenin ardından belirtmeniz gerekmektedir.
- ALINTI FORMATI: "Alıntı yapılan Cümle/ler" (Yıl, Yarışma Adı, Kategori, Takım Adı)
- ÖRNEK ALINTI: "Enkazda depremzedenin nerede olduğunu tespit edilememesi, enkaz kaldırma ve deprem-zede arama çalışmalarını yavaşlatan en önemli sorundur." (2020, İnsanlık Yararına Teknoloji Yarışması, Afet Yönetimi, X Takımı)
- Kaynakçada referanslar aşağıdaki şekilde belirtilebilir.
Dijital Kaynak: Yazarların Soyadı, Adlarının Baş Harfi., Yazının Başlığı, Yazının Tarihi, Erişim Tarihi, Erişim Adresi.
Basılı Kaynak: Yazarların Soyadı, Adlarının Baş Harfi., (Basım Tarihi) Yazının Başlığı, (Varsa) Yayınlandığı Derginin Adı, (Varsa) Derginin Sayısı, Sayfa numarası.

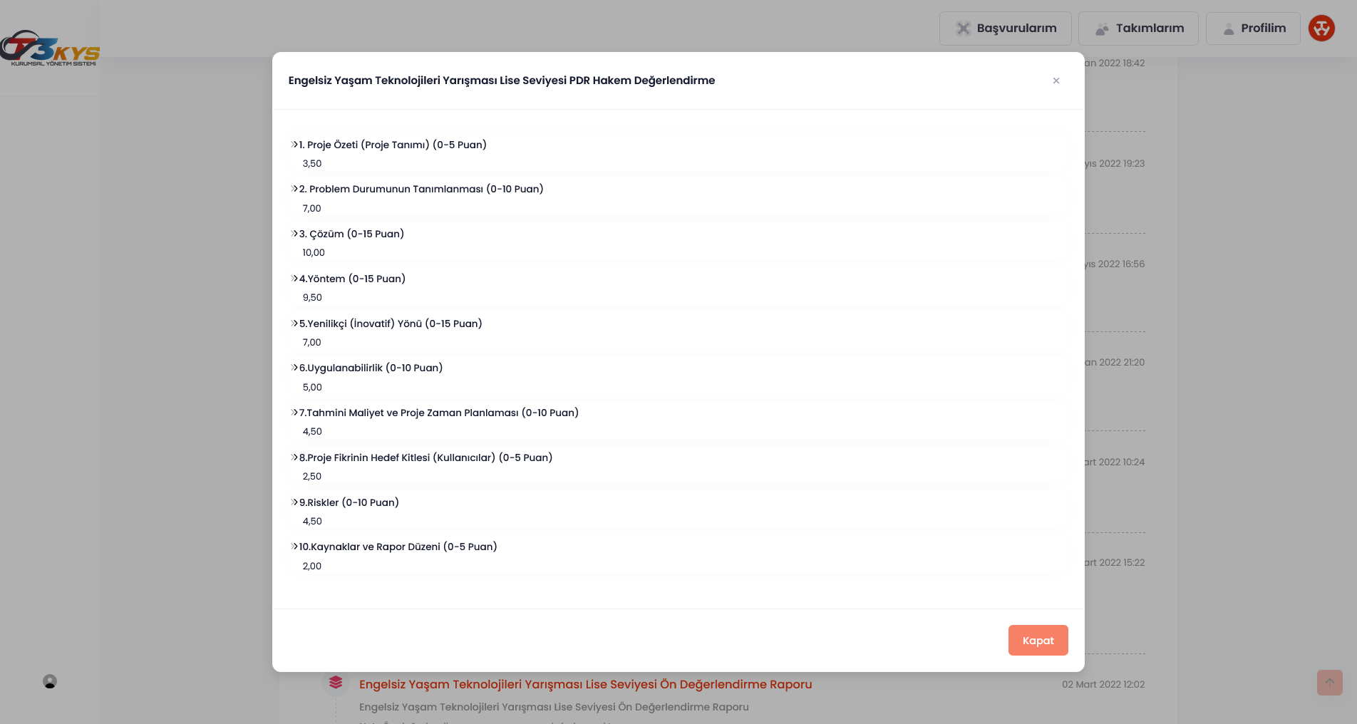
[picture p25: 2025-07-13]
5_Project_Documentation/Reports_and_Presentations/EGG proje detay raporu hakem puanlama.png

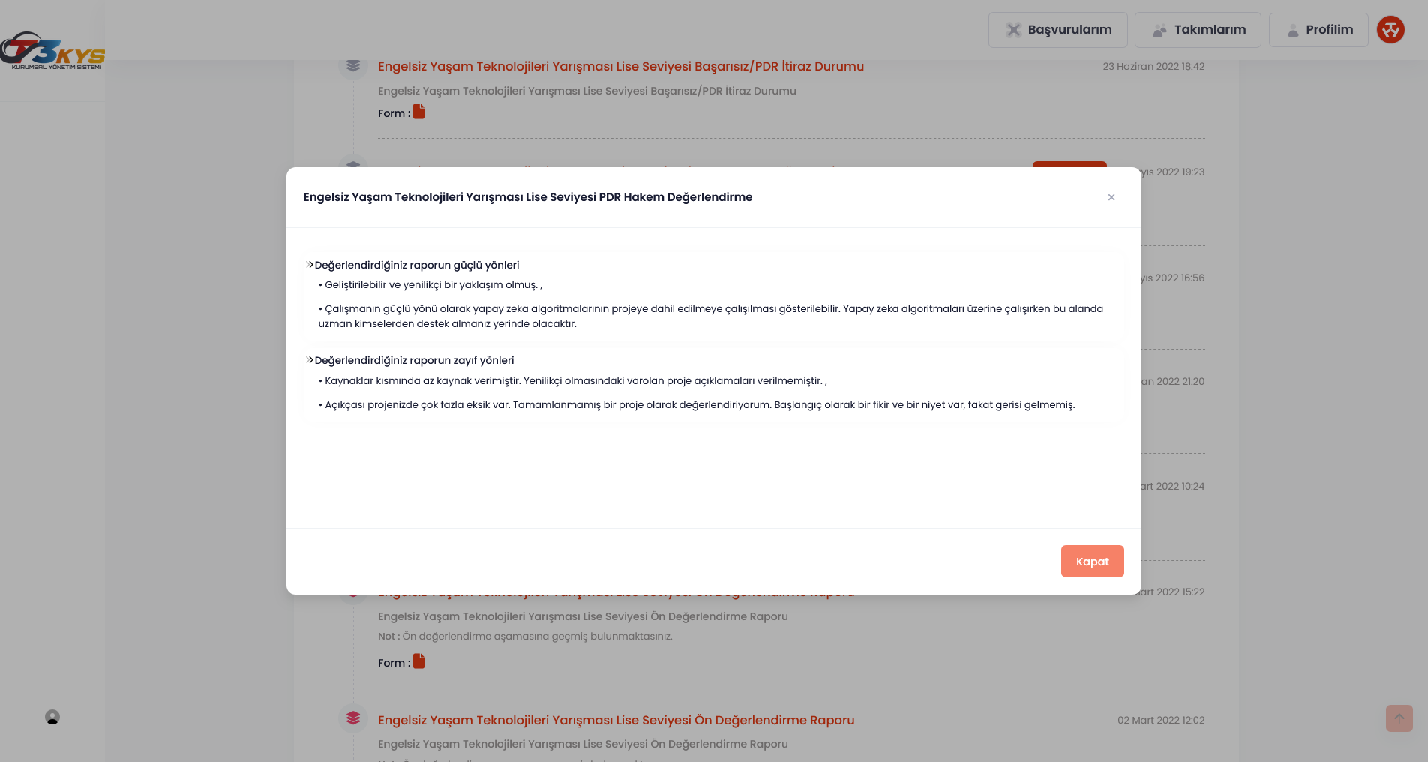
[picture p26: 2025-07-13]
5_Project_Documentation/Reports_and_Presentations/EGG proje detay raporu hakem değerlendirme.png

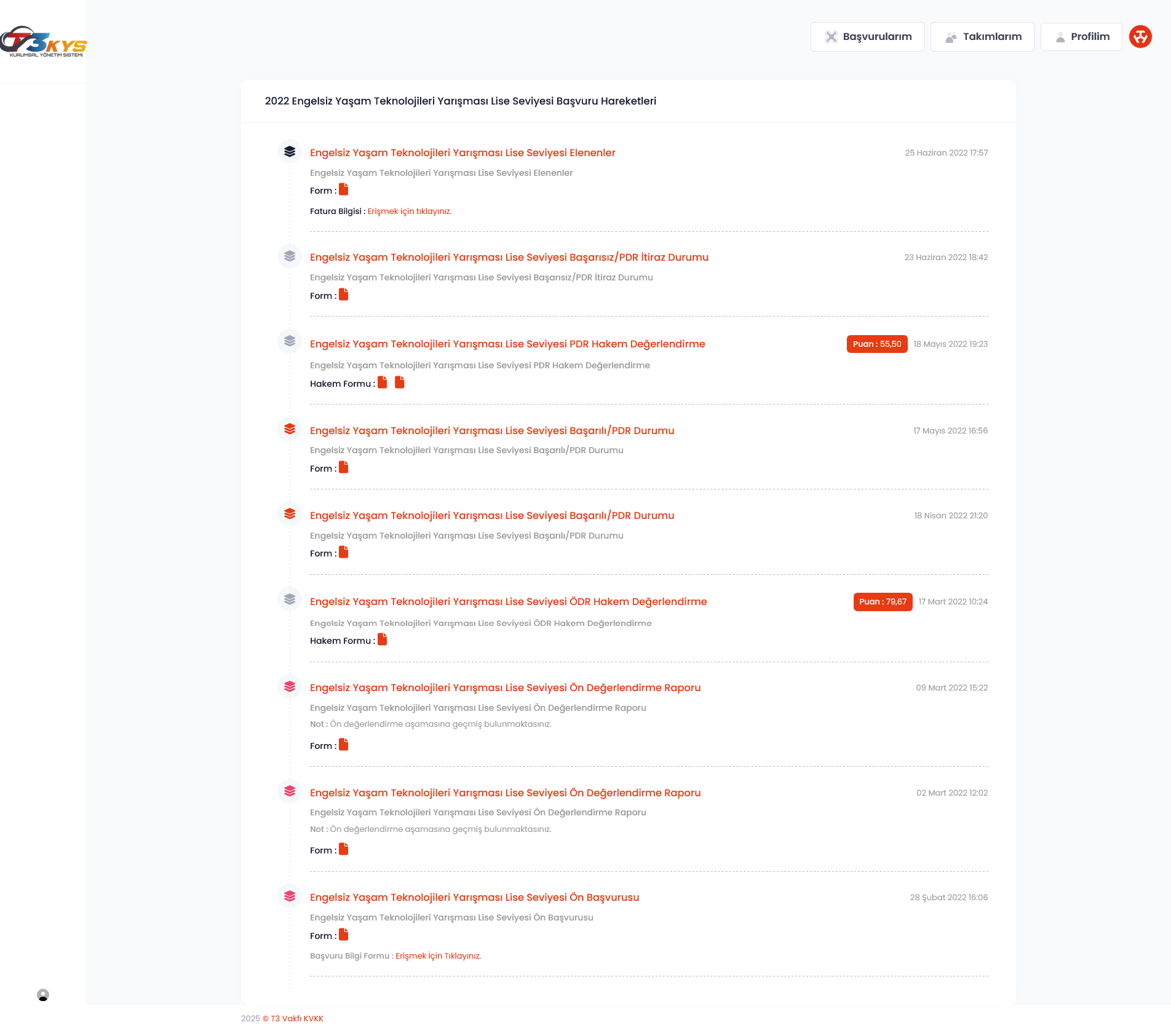
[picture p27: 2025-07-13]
5_Project_Documentation/Reports_and_Presentations/EGG proje genel süreç .png

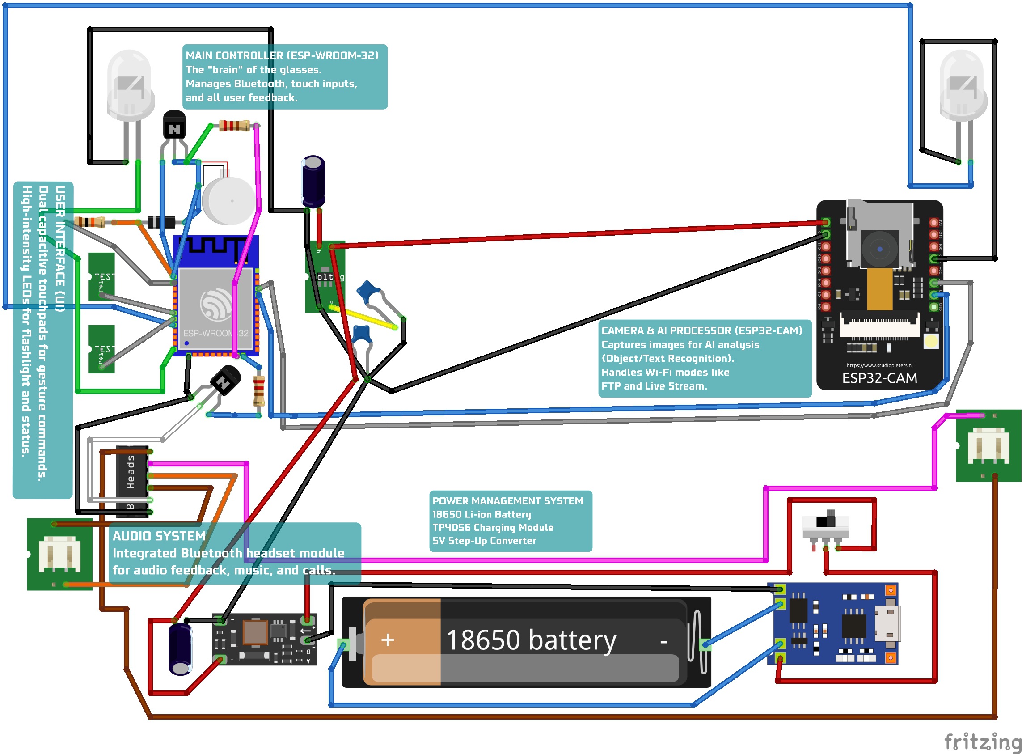
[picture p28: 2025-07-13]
1_Hardware_Design/gozluk-fiziksel-sema-noted.jpg

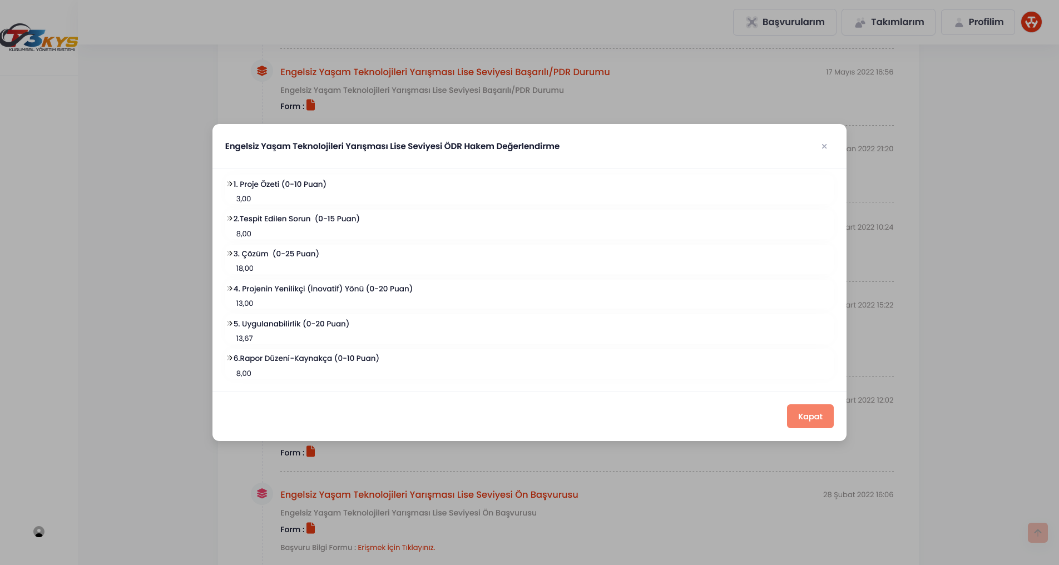
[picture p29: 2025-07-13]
5_Project_Documentation/Reports_and_Presentations/Engelsiz Yaşam Teknolojileri Yarışması Lise Seviyesi ÖDR Hakem Değerlendirme .png

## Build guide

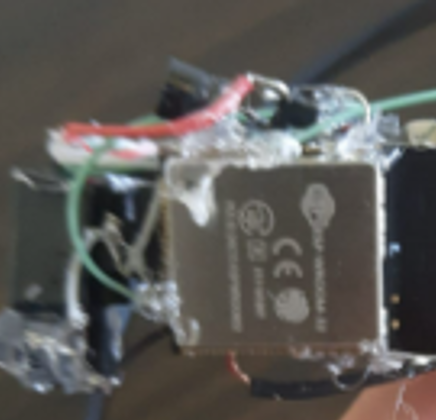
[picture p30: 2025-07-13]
5_Project_Documentation/Media/1_Prototyping_and_Assembly/esp32wrower-distan-gorunumu.png

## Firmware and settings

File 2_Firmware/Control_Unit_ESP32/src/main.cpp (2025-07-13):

//#include <SPI.h>
//#include <Wire.h>
//#include <Adafruit_GFX.h>
//#include <Adafruit_SSD1306.h>
#include <BluetoothSerial.h>
#include <ESP32Time.h>
#include "headers.h"
#include <analogWrite.h>
#include "soc/soc.h"
#include "soc/rtc_cntl_reg.h"

#define sw2 33
#define sw 32
#define solLed 12
#define sagLed 25
#define titresimMotoru 15
#define bluetoothKulaklik 26
//#define SCREEN_WIDTH 128
//#define SCREEN_HEIGHT 64
//#define OLED_RESET     -1 
//#define SCREEN_ADDRESS 0x3C

String SerialdenEnSonGelenKomut = "";
String BTdenEnSonGelenKomut = "";
//String sonEkranaYazilan = "";

//yuzey 1
int lastButtonState = HIGH;  
unsigned long lastDebounceTime = 0;  
unsigned long debounceDelay = 25;  
bool buttonState = HIGH; 
byte tapCounter; 
int timediff;
bool flag1, flag2;
long double presstime, releasetime; 



//bool ekranBaglandiMi = true;
int titremeSuresi = 300;
int titremeTekrarSayisi = 1;

int solLedParlaklik = 0;
int sagLedParlaklik = 0;
int komutIndexi = 0;
#define touchKalibreDegeri 19

bool kameraKartiBasladiMi = false;

BluetoothSerial BLUETOOTH;
ESP32Time rtc;

//Adafruit_SSD1306 display(SCREEN_WIDTH, SCREEN_HEIGHT, &Wire, OLED_RESET);
void bluetoothKulaklikTask(void *parameter){
  digitalWrite(bluetoothKulaklik,HIGH);
  vTaskDelay(3000 / portTICK_PERIOD_MS);
  digitalWrite(bluetoothKulaklik,LOW);
  vTaskDelete( NULL );
}
void bluetoothKulaklikStartStopTask(void *param){
  digitalWrite(bluetoothKulaklik,HIGH);
  vTaskDelay(100 / portTICK_PERIOD_MS);
  digitalWrite(bluetoothKulaklik,LOW);
  vTaskDelete( NULL );
}
void titresimMotoruTask(void *parameter){
  for(int i = 0;i<titremeTekrarSayisi;i++){
    digitalWrite(titresimMotoru,HIGH);
    vTaskDelay(titremeSuresi / portTICK_PERIOD_MS);
    digitalWrite(titresimMotoru,LOW);
    vTaskDelay(titremeSuresi / portTICK_PERIOD_MS);
  }
  vTaskDelete( NULL );
}
void titresimMotorunuSur(int _time,int _tekrarSayisi){
  titremeSuresi = _time;
  titremeTekrarSayisi = _tekrarSayisi;
 xTaskCreate(
                    titresimMotoruTask,          /* Task function. */
                    "TitresimMotoruTask",        /* String with name of task. */
                    1000,            /* Stack size in bytes. */
                    NULL,             /* Parameter passed as input of the task */
                    1,                /* Priority of the task. */
                    NULL);  
}
void bluetoothKulaklikSur(){
  
   xTaskCreate(
                    bluetoothKulaklikTask,          /* Task function. */
                    "BluetoothKulaklikTask",        /* String with name of task. */
                    1000,            /* Stack size in bytes. */
                    NULL,             /* Parameter passed as input of the task */
                    1,                /* Priority of the task. */
                    NULL);  
}
void btKulaklikStopStart(){
   xTaskCreate(
                    bluetoothKulaklikStartStopTask,          /* Task function. */
                    "BluetoothKulaklikStartStopTask",        /* String with name of task. */
                    1000,            /* Stack size in bytes. */
                    NULL,             /* Parameter passed as input of the task */
                    1,                /* Priority of the task. */
                    NULL);  
}
void btKulaklikReddetTask(void *param){
  digitalWrite(bluetoothKulaklik,HIGH);
  vTaskDelay(2170 / portTICK_PERIOD_MS);
  digitalWrite(bluetoothKulaklik,LOW);
  vTaskDelete( NULL );
}
void btKulaklikReddet(){
   xTaskCreate(
                    btKulaklikReddetTask,          /* Task function. */
                    "BtKulaklikReddetTask",        /* String with name of task. */
                    1000,            /* Stack size in bytes. */
                    NULL,             /* Parameter passed as input of the task */
                    1,                /* Priority of the task. */
                    NULL);  
}

int ikiNoktadanSonrakiSayiNedir(String _s){
  return _s.substring(_s.indexOf(":")+1).toInt();
}
void btKomutuUygula(String _komut){
  if(_komut.indexOf("solLed:") >= 0){
    solLedParlaklik = ikiNoktadanSonrakiSayiNedir(_komut);
    analogWrite(solLed,solLedParlaklik);
  }else if (_komut.indexOf("sagLed:") >= 0){
    sagLedParlaklik = ikiNoktadanSonrakiSayiNedir(_komut);
    analogWrite(sagLed,sagLedParlaklik);
  }else if(_komut.indexOf("ekran:") >= 0){
    //ekranaYazdir(_komut.substring(_komut.indexOf(":")+1));
  }else if(_komut.indexOf("titresimMotoru:") >= 0){
    titresimMotorunuSur(ikiNoktadanSonrakiSayiNedir(_komut),1);
  }else if(_komut.indexOf("bluetoothKulaklik") >= 0){
    bluetoothKulaklikSur();
  }else if(_komut.indexOf("ledleriDegereGetir:") >= 0){
    sagLedParlaklik = ikiNoktadanSonrakiSayiNedir(_komut);
    analogWrite(sagLed,sagLedParlaklik);
    solLedParlaklik = sagLedParlaklik;
    analogWrite(solLed,solLedParlaklik);
  }else if(_komut.indexOf("herseyiSifirla") >= 0){
    analogWrite(sagLed,0);
    analogWrite(solLed,0);
    sagLedParlaklik = 0;
    solLedParlaklik = 0;
    //ekranaYazdir("");
  }else if(_komut.indexOf("zaman:") >= 0){
    rtc.setTime(ikiNoktadanSonrakiSayiNedir(_komut));
    String temp = "zaman:"+ikiNoktadanSonrakiSayiNedir(_komut);
    Serial.println(temp);

  }else if(_komut.indexOf("mod") >= 0){
    Serial.println("mod");
  }else if(_komut.indexOf("ftpModu") >= 0){
    Serial.println("ftpModu");
  }else if(_komut.indexOf("normalMod") >= 0){
    Serial.println("normalMod");
  }else if(_komut.indexOf("yayinModu") >= 0){
    Serial.println("yayinModu");
  }else if(_komut.indexOf("ipAdressi") >= 0){
    Serial.println("ipAdressi");
  }else if(_komut.indexOf("zaman?") >= 0){
    BLUETOOTH.println(rtc.getTime("%F %H.%M.%S"));
  }else{
    Serial.println(_komut);
  }
}
void bt_callback_function(esp_spp_cb_event_t event, esp_spp_cb_param_t *param) {
  if (event == ESP_SPP_START_EVT) {
  }
  else if (event == ESP_SPP_SRV_OPEN_EVT ) {
    //bağlanıldığında


  }
  else if (event == ESP_SPP_CLOSE_EVT  ) {
    //disconn
  }
  else if (event == ESP_SPP_DATA_IND_EVT ) {
    BTdenEnSonGelenKomut = BLUETOOTH.readString();
    btKomutuUygula(BTdenEnSonGelenKomut);

  }
}




void setup() {
  WRITE_PERI_REG(RTC_CNTL_BROWN_OUT_REG, 0);
  Serial.begin(115200); //for serial monitor
  Serial.setTimeout(10);
  BLUETOOTH.begin("AkıllıGözlük");
  BLUETOOTH.setTimeout(10);
  pinMode(solLed, OUTPUT);
  pinMode(sagLed, OUTPUT);
  pinMode(titresimMotoru, OUTPUT);
  pinMode(bluetoothKulaklik, OUTPUT);
  BLUETOOTH.register_callback(bt_callback_function);
 

 /*if(!display.begin(SSD1306_SWITCHCAPVCC, SCREEN_ADDRESS)) {
    Serial.println(F("SSD1306 allocation failed"));
    ekranBaglandiMi = false;
  }else{
  display.display();
  display.clearDisplay();
  display.setTextSize(1);
  display.setTextColor(WHITE);
  display.setCursor(0,28);
  display.println("");
  display.display();
  }*/

}

void hataTitremesi(){
  titresimMotorunuSur(250,2);
}
void olumluTitreme(){
  titresimMotorunuSur(250,1);
}
void komutIndexiKontrolcusu(){
  unsigned long baslangictakiSure = millis();
  unsigned long basilmaSuresi;
  int touchDegeri = touchRead(sw2);
  if(touchDegeri<touchKalibreDegeri){
  delay(5);
  touchDegeri = touchRead(sw2);
  if(touchDegeri<touchKalibreDegeri){
  touchDegeri = touchRead(sw2);
  while(touchDegeri<touchKalibreDegeri){
    touchDegeri = touchRead(sw2);
  }
  basilmaSuresi =  millis() - baslangictakiSure;
  if(basilmaSuresi>=1000){
   komutIndexi = 0;
   titresimMotorunuSur(1000,1);
  }else if(basilmaSuresi>=30){
    if(komutIndexi<3){
    komutIndexi++;
    }else{
      komutIndexi = 0;
      titresimMotorunuSur(1000,1);
    }
  }

  }
  }
}
void komutuUygula(String _komut){
  if(_komut.indexOf("kartBasladi")>= 0){
    kameraKartiBasladiMi = true;
    String temp ="zaman:" + String(rtc.getEpoch());
    Serial.println(temp);
  }else if(_komut.indexOf("kartKapandi") >= 0){
    kameraKartiBasladiMi = false;
  }else if(_komut.indexOf("196.168") >= 0){
    String temp = "ipAdressi:"+_komut;
    BLUETOOTH.println(temp);
  }else if(_komut.indexOf("fotografCekilemedi") >= 0){
    hataTitremesi();
    BLUETOOTH.println(_komut);
  }else if(_komut.indexOf("kameraHatasi") >= 0){
    hataTitremesi();
    BLUETOOTH.println(_komut);
  }
  else if(_komut.indexOf("fotografCekildi") >= 0){
    olumluTitreme();
    BLUETOOTH.println(_komut);
  }else if(_komut.indexOf("SDhatasi") >= 0){
    hataTitremesi();
    BLUETOOTH.println(_komut);
  }else if(_komut.indexOf("ZamanAsimi") >= 0){
    hataTitremesi();
    BLUETOOTH.println(_komut);
  }else if(_komut.indexOf("SunucuyaAtilamadi") >= 0){
    hataTitremesi();
    BLUETOOTH.println(_komut);
  }else if(_komut.indexOf("200") >= 0){
    olumluTitreme();
    BLUETOOTH.println(_komut);
  }
  else{
    BLUETOOTH.println(_komut);
  }

}
/*void ekranaYazdir(String _s){
  if(ekranBaglandiMi){
  if(sonEkranaYazilan != _s){
  display.clearDisplay();
  display.setTextSize(1);
  display.setTextColor(WHITE);
  display.setCursor(0,0);
  display.println(_s);
  display.display();
  sonEkranaYazilan = _s;
  }
  }
}*/


void loop() {
  if(Serial.available() > 0){
    SerialdenEnSonGelenKomut = Serial.readString();
    komutuUygula(SerialdenEnSonGelenKomut);
  }
  //yuzey bir 
  int readingOne = 0;
  if(touchRead(sw)>19){
    readingOne = 1;
  }
  if (readingOne != lastButtonState) {
    lastDebounceTime = millis();
  }
  
  if ((millis() - lastDebounceTime) > debounceDelay) {
    if (readingOne != buttonState) {
      buttonState = readingOne;
    }
  }
  if (buttonState == 0 && flag2 == 0)
  {
    presstime = millis(); 
    flag1 = 0;
    flag2 = 1;
    tapCounter++;
  }
  if (buttonState == 1 && flag1 == 0)
  {
    releasetime = millis(); 
    flag1 = 1;
    flag2 = 0;

    timediff = releasetime - presstime; 
  }
  if ((millis() - presstime) > 400 && buttonState == 1) 
  {
    if (tapCounter == 1)
    {
      if (timediff >= 400)
      {
        hold(); 
      }
      else
      {
        singleTap(); 
        }
    }else if (tapCounter ==2){
      doubleTap();
    }
    else if (tapCounter == 3) 
    {
      tripleTap(); 
    }
    tapCounter = 0;
  }
  lastButtonState = readingOne;

komutIndexiKontrolcusu();
  
}
void singleTap()
{
  BLUETOOTH.println("asistan");
  titresimMotorunuSur(100,1);
}
void doubleTap()
{
  doubleTapIndexYonlendiricisi();
  titresimMotorunuSur(100,2);
}
void tripleTap()
{
  tripleTapIndexYonlendiricisi();
  titresimMotorunuSur(100,3);
}
void hold()
{
  holdTapIndexYonlendiricisi();
  titresimMotorunuSur(1000,1);
}

void doubleTapIndexYonlendiricisi(){
  switch ( komutIndexi )
  {
  case 0:
  Serial.println("fotografCek");
  break;
  case 1:
  btKulaklikStopStart();
  break;
  case 2:
  Serial.println("fotografiYukle:fotograf-analizi/");
  break;
  case 3:
  Serial.println("fotografiYukle:para-tespiti/");
  break;
  }
}
void tripleTapIndexYonlendiricisi(){
  switch ( komutIndexi )
  {
  case 0:
  Serial.println("yayinModu");
  break;
  case 1:
  btKulaklikReddet();
  break;
  case 2:
  Serial.println("fotografiYukle:ocr/");
  break;
  case 3:
  Serial.println("fotografiYukle:yuz-tanima/");
  BLUETOOTH.println("yuzTanima");
  break;
  }
}

void ledDurumuDegistir(){
if(solLedParlaklik<255 || sagLedParlaklik<255){
    solLedParlaklik = 255;
    sagLedParlaklik = 255;
    analogWrite(sagLed,255);
    analogWrite(solLed,255);
  }else{
    solLedParlaklik = 0;
    sagLedParlaklik = 0;
    analogWrite(sagLed,0);
    analogWrite(solLed,0);   
  }
}
void holdTapIndexYonlendiricisi(){
  switch ( komutIndexi )
  {
  case 0:
  ledDurumuDegistir();
  break;
  case 1:
  bluetoothKulaklikSur();
  break;
  case 2:
  Serial.println("fotografiYukle:ocr/");
  BLUETOOTH.println("ceviriModu");
  break;
  case 3:
  BLUETOOTH.println("neredeyim");
  break;
  }
}

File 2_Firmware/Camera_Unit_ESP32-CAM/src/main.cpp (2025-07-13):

#include <Arduino.h>
#include "esp_camera.h"
#include "esp_http_client.h"
#include <WiFi.h>
#include <ArduinoWebsockets.h>
#include <WiFiClient.h>
#include "ESP32FtpServer.h"
#include "Base64.h"
#include "mbedtls/base64.h"
#include <Preferences.h>
#define CAMERA_MODEL_AI_THINKER
#define RECONNECT_TRY_TIMES 25
#include "camera_pins.h"
#include "headers.h"
#include <esp_sleep.h>
#include <driver/uart.h>
#include <ESP32Time.h>
#include "soc/soc.h"
#include "soc/rtc_cntl_reg.h"
#include "driver/rtc_io.h"

String komut = "";
String aktifOlanMod = "normalMod";
Preferences preferencesNesnesi;

const char *ssid = "AkilliCihazlar";
const char *password = "salakschedar";

const char *websocket_server_host = "3.67.198.158";
uint16_t websocket_server_port = 65080;

ESP32Time rtc;
camera_fb_t *fb = NULL;
void setCameraParam(int paramInt)
{
  sensor_t *s = esp_camera_sensor_get();
  s->set_quality(s, 10);
  switch (paramInt)
  {
  case 5:
    s->set_framesize(s, FRAMESIZE_QVGA);
    s->set_quality(s, 30);
    break;
  case 4:
    s->set_framesize(s, FRAMESIZE_UXGA);
    break;

  case 3:
    s->set_framesize(s, FRAMESIZE_SXGA);
    break;

  case 2:
    s->set_framesize(s, FRAMESIZE_XGA);
    break;

  case 1:
    s->set_framesize(s, FRAMESIZE_SVGA);
    break;

  case 0:
  default:
    s->set_framesize(s, FRAMESIZE_VGA);
    break;
  }
}
void disableWifi()
{
  WiFi.disconnect(true);
  WiFi.mode(WIFI_OFF);
}
void enableWifi()
{
  WiFi.disconnect(false);
  WiFi.mode(WIFI_STA);
}
void wifiInit()
{
  if (WiFi.status() != WL_CONNECTED)
  {
    enableWifi();
    WiFi.begin(ssid, password);
    int i = 0;
    while (WiFi.status() != WL_CONNECTED)
    {
      delay(500);
      i++;
      if (i >= RECONNECT_TRY_TIMES)
      {
        Serial.println("ZamanAsimi");
        normalModaGec();
      }
    }
  }
}
void ftpModunaGec()
{
  preferencesNesnesi.putString("aktifOlanMod", "ftpModu");
  disableWifi();
  Serial.println("kartKapandi");
  ESP.restart();
}
void webSocketYayinModunaGec()
{
  preferencesNesnesi.putString("aktifOlanMod", "webSocketYayinModu");
  disableWifi();
  Serial.println("kartKapandi");
  ESP.restart();
}
void normalModaGec()
{
  preferencesNesnesi.putString("aktifOlanMod", "normalMod");
  Serial.println("kartKapandi");
  ESP.restart();
}
bool createDir(fs::FS &fs, const char *path)
{
  if (fs.mkdir(path))
  {
    return true;
  }
  else
  {
    return false;
  }
}
void kameraInit()
{
  camera_config_t config;
  config.ledc_channel = LEDC_CHANNEL_0;
  config.ledc_timer = LEDC_TIMER_0;
  config.pin_d0 = Y2_GPIO_NUM;
  config.pin_d1 = Y3_GPIO_NUM;
  config.pin_d2 = Y4_GPIO_NUM;
  config.pin_d3 = Y5_GPIO_NUM;
  config.pin_d4 = Y6_GPIO_NUM;
  config.pin_d5 = Y7_GPIO_NUM;
  config.pin_d6 = Y8_GPIO_NUM;
  config.pin_d7 = Y9_GPIO_NUM;
  config.pin_xclk = XCLK_GPIO_NUM;
  config.pin_pclk = PCLK_GPIO_NUM;
  config.pin_vsync = VSYNC_GPIO_NUM;
  config.pin_href = HREF_GPIO_NUM;
  config.pin_sscb_sda = SIOD_GPIO_NUM;
  config.pin_sscb_scl = SIOC_GPIO_NUM;
  config.pin_pwdn = PWDN_GPIO_NUM;
  config.pin_reset = RESET_GPIO_NUM;
  config.xclk_freq_hz = 20000000;
  config.pixel_format = PIXFORMAT_JPEG;

  config.frame_size = FRAMESIZE_UXGA;
  config.jpeg_quality = 10;
  config.fb_count = 2;

  // camera init
  esp_err_t err = esp_camera_init(&config);
  if (err != ESP_OK)
  {
    Serial.println("kameraHatasi");
    return;
  }
}
esp_err_t _http_event_handler(esp_http_client_event_t *evt)
{
  Serial.println("");
  switch (evt->event_id) {
    case HTTP_EVENT_ERROR:
    Serial.println("SunucuyaAtilamadi");
      break;
    case HTTP_EVENT_ON_CONNECTED:
      break;
    case HTTP_EVENT_HEADER_SENT:
    Serial.println("200");
    //s
      break;
    case HTTP_EVENT_ON_HEADER:
    //s
      break;
    case HTTP_EVENT_ON_DATA:
      break;
    case HTTP_EVENT_ON_FINISH:
      break;
    case HTTP_EVENT_DISCONNECTED:
    //sa
      break;
  }
  return ESP_OK;
}
static esp_err_t cekVeSunucuyaYukle(String Amac)
{
  fb = NULL;
  esp_err_t res = ESP_OK;


 
  fb = esp_camera_fb_get();
  if (!fb) {
    return ESP_FAIL;
  }
  
   
 int image_buf_size = 4000 * 1000;                                                  
 uint8_t *image = (uint8_t *)ps_calloc(image_buf_size, sizeof(char));
 size_t length=fb->len;
 size_t olen;
wifiInit();
 int err1 = mbedtls_base64_encode(image, image_buf_size, &olen, fb->buf, length);
 esp_http_client_handle_t http_client;
  esp_http_client_config_t config_client = {0};
   String post_url2 =  "https://xvenofsk9b.execute-api.eu-central-1.amazonaws.com/prod/";
   post_url2.concat(Amac);
   char post_url3[post_url2.length() + 1];
   post_url2.toCharArray(post_url3, sizeof(post_url3));
  
  config_client.url = post_url3;
  config_client.event_handler = _http_event_handler;
  config_client.method = HTTP_METHOD_POST;
  config_client.timeout_ms= 40000;
  http_client = esp_http_client_init(&config_client);

   esp_http_client_set_post_field(http_client, (const char *)fb->buf, fb->len);
  

  esp_http_client_set_header(http_client, "Content-Type", "image/jpeg");

  esp_err_t err = esp_http_client_perform(http_client);
  if (err == ESP_OK) {
    Serial.println(esp_http_client_get_status_code(http_client));
  }

  esp_http_client_cleanup(http_client);

  esp_camera_fb_return(fb);
}

bool fotografCekVeKaydet()
{
  fb = esp_camera_fb_get();
  if (!fb)
  {
    return false;
  }
  String dirPath = "/resimler/" + rtc.getTime("%F");
  if (!createDir(SD_MMC, dirPath.c_str()))
  {
    return false;
  }
  String path = dirPath + "/RESIM" + rtc.getTime("_%FZ_%H.%M.%S") + ".jpg";
  fs::FS &fs = SD_MMC;
  File file = fs.open(path.c_str(), FILE_WRITE);
  if (!file)
  {
    return false;
  }
  else
  {
    file.write(fb->buf, fb->len);
  }
  file.close();
  esp_camera_fb_return(fb);
  return true;
}
void kaydedilenAyarlariAyarla(){
preferencesNesnesi.begin("mod", false);
aktifOlanMod = preferencesNesnesi.getString("aktifOlanMod");

}
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
